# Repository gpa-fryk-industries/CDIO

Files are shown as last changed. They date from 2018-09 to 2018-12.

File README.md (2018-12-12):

# CDIO

## Hardware
Altium project and libraries are located in `hw/`. Schematics are available as PDF in `hw/board/`.

## Firmware
The firmware is split up in two. The MCU in `fw/mcu` and the FPGA in `fw/ice`. The README in `fw/` explains the 
configuration routine used for the FPGA.

See `fw/mcu/README-md` for instruction on how to compile the MCU firmware and dependencies.

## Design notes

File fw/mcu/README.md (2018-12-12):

# MCU Firmware

## src/
Main code directory

### fpga/
Contains code related to the FPGA

### fdt/
Contains code related to the device tree config file

### radio/
Contains code related to the radio

## Dependencies

### arm-non-eabi-*
Compiler used.

### device-tree-compiler
Used to compile the config.dts file into a flattened device tree binary read by the MCU during runtime. 

### Libopencm3
Open source ARM Cortex-M microcontroller library http://libopencm3.org/.
Included as a submodule in /fw/mcu/libopencm3.

**MUST BE COMPILED AFTER CLONING!**

### SPIRIT1_Library
Low level support library for radio. Located in /fw/mcu/radio/SPIRIT1_Library
Does not need to be compiled, included as-is.

## Compilation

### Install dependencies
All dependencies must be installed and in case of libopencm3, compiled.

### Run cmake
Run `cmake .` in the project root folder (not here). If successfully it should look something like this:
```
INFO * * * Device information * * *
INFO Device:	stm32l082kbu
INFO	family:	stm32l0 (stm32l082kbu)
INFO	cpu:	cortex-m0plus
INFO	fpu:	soft
INFO	flags:	-DSTM32L0 -DSTM32L082KBU
INFO	defs:	-DSTM32L0 -DSTM32L082KBU -D_ROM=128K -D_RAM=20K -D_ROM_OFF=0x08000000 -D_RAM_OFF=0x20000000
INFO libopencm3 libs: opencm3_stm32l0
INFO DTS @ /home/atmelfan/projects/CDIO/fw/mcu/src 
INFO FPGA CONFIGURATION @ /home/atmelfan/projects/CDIO/fw/mcu/src/fpga/fpga_conf.bin
-- Configuring done
-- Generating done
-- Build files have been written to: /home/atmelfan/projects/CDIO/cmake-build-debug
```

If device information is completely or partially empty, libopencm3 has most likely not been compiled properly or at the right location.

The `DTS @ <directory>` message should list the directory of the config.dts file.

The `FPGA CONFIGURATION @ <file>` message should specify the used FPGA configuration image.

### Compile
Run `make all`

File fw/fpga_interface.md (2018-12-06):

# FPGA Interface

## Physical
Pin assignments:

### Control signals
Pin names are written as `[HDL name]/[Schematic name]` when they do not match.

#### MCO_CLK/FPGA_GCLK 

FPGA clock. Is feed from the MCU using its MCO (Mcu Clock Out) functionality. 
Is divided by 2 from the MCU base clock of 4 MHz to 2 MHz. May be turned of in sleep mode.

#### RST/FPGA_RST
Resets the FPGA state. 

**Note** that ths is different from the CRESET pin below which is used to reset FPGA configuration!

#### ATT/FPGA_ATT
Interrupt request from the FPGA

#### MINH/FPGA_MINH
Master Inhibit. Not currently used. 

Reserved to inhibit the FPGA from behaving as master in a dual master system.

### SPI / config signals

#### SPI_SS/FPGA_CSS
SPI slave select. Selects the FPGA in both configuration mode and during normal operation. Active **LOW**.

#### SPI_SI/MOSI
SPI serial input.

#### SPI_SO/MISO
SPI serial output.

#### SPI_SCK/SCK
SPI serial clock.

#### CRESET/FPGA_CRESET
FPGA configuration reset. Resets configuration so that a new can be uploaded to config memory.

#### CDONE/FPGA_CDONE
FPGA configuration done. Indicates that configuration has been completed without error.

### Microphone signals

#### MIC_DAT/PDMD
Mic data. PDM encoded.

#### MIC_CLK/PDMC
Mic clock. Driven at 2 MHz when microphone is enabled.

### Speaker signals

#### SPK_R/PWMR 
Main speaker, right halfbridge PWM. 

#### SPK_L/PWML 
Main speaker, left halfbridge PWM. 

#### SPK_A/PWMA 
Aux speaker PWM. 

## Layout

The FPGA acts as a SPI slave with read/write registers. 

The first byte transferred contains a read or write bit (RW bit) and address. 

[0x00-0x3F - Config registers][0x40-0x7F - Data registers]

### Register read

1. Send address with MSB = 1
2. Read back

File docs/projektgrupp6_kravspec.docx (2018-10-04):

# Kravspecifikation

David Frykskog, Gustav Palmqvist

Version 3.0

# Status

Granskad
Godkänd

# PROJEKTIDENTITET

Grupp 6, 2018/HT, Deepoid AB CDIO
Linköpings Tekniska Högskola, ITN

# Gruppdeltagare

Namn | Ansvar | Telefon | E-post
Gustav Palmqvist | Projektledare (PL) | 070-455 84 40 | guspa885@student.liu.se
David Frykskog | Dokumentansvarig (DOK) | 070-372 27 11 | davfr422@student.liu.se

Kund: Deepoid AB, 583 30 Linköping,
Kontaktperson hos kund: Anders Brodin, 070-310 44 48 , anders@deepoid.com
Kursansvarig: Ole Pedersen, 011-36 32 61, ole.pedersen@liu.se
Handledare: Ole Pedersen, 011-36 32 61, ole.pedersen@liu.se

# Dokumenthistorik

Version | Datum | Utförda förändringar | Utförda av | Granskad
1.0 | 2018-09-06 | Första utkast | davfr422, guspa885
2.0 | 2018-09-23 | Revision 1 | davfr422, guspa885
3.0 | 2018-10-04 | Revision 2 | davfr422

# 1 Inledning

Deepoid AB i Linköping är ett företag som utvecklar och tar fram utrustning för dykarmarknaden. Företaget vill ta fram en prototyp för radiokommunikation mellan snorklare. Prototypen ska fungera för kommunikation på minst 100 meters avstånd och ska vara av lågenergityp. I huvudsak ska den första prototypen användas i labbmiljö, i syfte att vara ett underlag för en eventuell produkt.

## 1.1 Parter

Beställaren av prototypen är Deepoid AB och utförarna är civilingenjörsstudenter i elektronikdesign, år 5 (se författarna till dokumentet). Handledare från Linköpings universitet är även delaktiga för avstämning på handledningsmöten under projektets gång.

## 1.2 Mål

Målet med projektet är att utveckla en prototyp för radiokommunikation mellan snorklare. Företaget, eller beställaren vill ta del av prototypen i syfte att kunna utveckla det till en produkt.

## 1.3 Användning

Till en början ska prototypen som tidigare nämnt fungera som underlag för att utveckla en produkt för snorklare.

## 1.4 Definitioner

- AF – Audio Front end
- MCU – Microcontroller Unit
- FPGA/CPLD – Field-Programmable Gate Array/Complex-Programmable Logic Device
- PSU – Power Supply Unit
- RF – Radio Frequency / Radio Front end
- DSP – Digital Signal Processing
- ADC – Analog to Digital Converter
- DAC – Digital to Analog Converter
- D-DAC – DAC med klass D utgångssteg.

# 1 Översikt av systemet

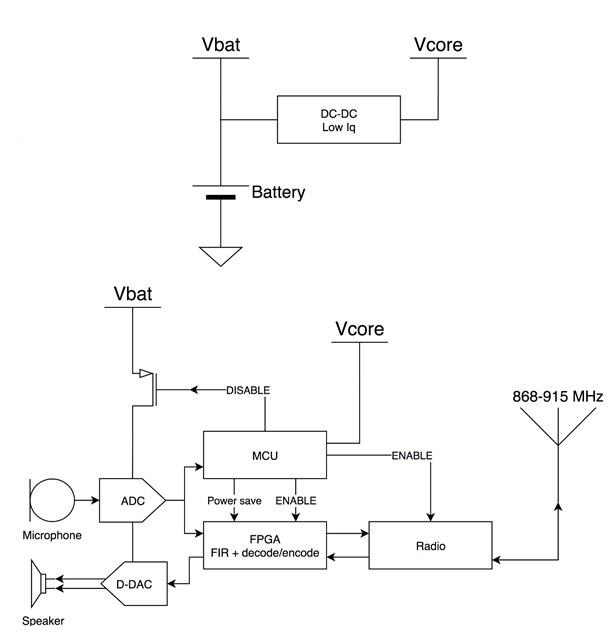
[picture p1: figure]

Figur 1: Översikt av systemet

## 1.1 Produktkomponenter

Som resultat av projektet kommer produkten bestå av flera prototyper mjukvara, underlag i form av layout och schema samt dokumentation. Fler än två prototyper är nödvändigt för att testa kommunikation inom grupp.

## 1.2 Beroenden till andra system

Systemet beror endast på andra enheter av samma typ (dvs inom sitt eget system).

## 1.3 Ingående delsystem

Prototypen består övergripligt av komponenter beskrivet i figur 1. Dessa monteras på ett PCB.

### 1.3.1 AF – Audio Front end

Består av mikrofon, högtalare, ADC och DAC med tillhörande förstärkare.

### 1.3.2 MCU – MicroController Unit

Mikrokontroller kontrollerar att samtliga enheter fungerar tillsammans samt sköter initialisering av systemet. MCU:n kommer majoriteten av tiden befinnas i sömnläge för att minimera strömförbrukning.

### 1.3.3 FPGA/CPLD – Field Programmable Gate Array

Strömsnål signalbehandlingsenhet som sköter filtrering (FIR) och formatering/paketering av en full duplex ljudström. Detta för att undvika utföra DSP i MCU:n vilket skulle kräva en kraftigare MCU med tillbehörande strömförbrukning.

### 1.3.4 PSU – Power Supply Unit

Strömförsörjningsenhet. Består av laddare till batteri och spänningsregulator till övrig elektronik.

### 1.3.5 RF – Radio Front end

Består av en tidigare godkänd radiomodul.

## 1.4 Avgränsningar

Systemet behöver inte ha någon specifik formfaktor (dvs. den behöver ej uppfylla något krav på form eller vikt) eller gå att använda i något annat än en testmiljö (under vatten).

## 1.5 Designfilosofi

Varje delsystem skall vara integrerat på ett kort men om möjligt vara tillräckligt isolerade så att om ett av delsystemen inte fungerar så ska det fortfarande gå att testa de andra. Det finns även en ekonomisk aspekt i val av hårdvara.

## 1.6 Generella krav på hela systemet

I detta dokument kommer alla krav att beskrivas med en tabellrad enligt nedan. Kravnummer kommer att vara löpande genom hela dokumentet. Kolumn två talar om att det är ett originalkrav eller om det har reviderats. Hänvisning till beslut om revidering ska finns. I kolumn 3 finns själva lydelsen av kravtexten. I sista kolumnen finns dess prioritet beskriven.

| Original | Systemet ska hantera röstkommunikation mellan enheter (multicasting). | Bas
| Original | Röstkommunikation ska alltid vara på, ingen ”push to talk”. | Bas
| Original | Minimal räckvidd: 100 m. | Bas
| Original | Önskat räckvidd: 500+ m. | Extra
| Original | Minimal batteritid: 10 h per enhet med kontinuerligt samtal. | Bas
| Original | Ska kunna hantera bruten kommunikationslänk och återansluta. | Bas
| Original | Systemet ska med enkelhet kunna bli godkänt av CE/FCC. | Bas
| Original | Användare anslutna till samma grupp/kanal ska endast kunna kommunicera inom gruppen/kanalen. | Bas
| Original | Minimalt röstspektrum: 300 – 3400 KHz | Bas
| Original | Skall inte använda kretsar som tillverkaren har markerad som ’Not recommended for new designs’ / NRND. | Extra

# 2 AF – Audio Front-end

Ljud-delsystemet kommer bestå av två komponenter.

- En ADC med 3.5mm ingång alternativt en mikrofon och förstärkare.
- En DAC med 3.5mm utgång alternativt en högtalare och förstärkare (klass D). Högtalaren har inga krav på effekt.

Två 3.5mm kontakter bör prioriteras då mikrofon och högtalare ej är ett krav och underlättar utveckling.

Audio front-end har som uppgift att omvandla den digitala ljudströmmen till dess analoga motsvarighet i båda riktningar.

För att uppfylla krav #5 så måste denna front end vara energieffektiv och gå att stänga av för att maximera batteritiden.

| Original | Energieffektiv audio front-end med avstängning. Derivat av krav #5. | Bas
| Original | ADC + DAC med minst 8 KHz samplingsfrekvens för röstkommunikation. | Bas
| Original | 3.5 mm kontakter för ljud in/ut under utveckling. | Bas
| Original | Integrerad mikrofon + högtalare med förstärkare. | Extra
| Original | Skall inte ta överhettas under normal användning. | Rev. 2

# 3 MCU

Mikrokontrollerenheten består av en mikrokontroller som sköter kontroll av samtliga enheter. Den har även uppgiften att initialisera FPGA:n.

Krav nr 16 D | Original | Mikrokontrollern ska kunna drivas på 1.8 V. | Bas
| Original | Mikrokontrollern ska befinna sig i sömnläge tills den triggas av en interrupt. | Bas

# 4 FPGA/CPLD

Krav nr 18 D | Original | Vid uppstart ska programvaran laddas över från MCU:n. | Bas
| Original | Ska kunna strömma ut data till radioenheten. | Bas
| Original | Ska sköta DSP av informationsbärande signaler för att avlasta MCU. DSP inkluderar LP filtrering, formatering och möjligen CRC av audio strömmen. | Bas

# 5 PSU

Krav nr 21 D | Original | Systemet ska kunna vara batteridrivet. | Bas
| Original | Batteriet ska kunna laddas genom USB. | Bas
Krav nr 23 F | Original | Switch-mode omvandlaren ska ha en effektivitet över 85% | Bas

# 6 RF – Radio Front end

Enligt krav nr 7 ovan så ska produkten gå att enkelt godkänna enligt FCC/CE krav vilket innebär att radiomodulen måste vara kompatibel med dessa krav. Detta kan undvikas genom att använda en redan godkänd modul.

Krav nr 24 D | Original | Ska bestå av CE/FCC godkänd modul. | Bas
| Original | Ska använda sig av 868 MHz / 915 MHz banden. | Bas
| Original | Radion ska gå att stänga av eller sättas i strömsparläge för att minimera effektförbrukning. | Extra

# 7 Prestandakrav

Hänvisar läsaren till generella krav på hela systemet (kap. 2.6).

# 8 Krav på möjlighet att uppgradera

| Original | Systemet ska kunna vidareutvecklas. | Bas

# 9 Ekonomi

| Original | Enhetskostnaden bör minimeras. | Extra

# 10 Krav på säkerhet

| Original | Batteriladdning får ej överladda batteriet eller djupurladda vilket kan leda till att batteriet fallerar. | Extra

# 11 Leveranskrav och delleveranser

| Original | Delleverans 2018-10-16: Layout och hårdvarubeställning. | Bas
| Original | Delleverans 2018-11-06: Hårdvara färdigställd. | Bas
| Original | Projektavslut 2018-12-18: Färdig prototyp. | Bas

# 12 Dokumentation

| Original | Första kravspecifikation färdig 2018-09-18. | Bas
| Original | Projektplan färdig 2018-09-18. | Bas
| Original | Tidsplan färdig 2018-09-18. | Bas
| Original | Projektrapport färdig 2019-01-07. | Bas

Projektkurs, CDIO. Projektgrupp 6 LIPs David Frykskog davfr422@student.liu.se Sida 13

LiTH Deepoid AB CDIO

LiTH Deepoid AB CDIO 2018-10-04

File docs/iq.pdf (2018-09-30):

Component | Name | Url/artnr | Manufacturer | Distributor | Cost, 1pc [USD]
FPGA | ICE40UP5K-SG48I | 842-40UP5KSG48ITR | Lattice | Mouser | 7,42
MCU | STM32L011F4U6TR | 511-STM32L011F4U6TR | STMicroelectronics | Mouser | 1,51
ADC | FAN3850AUC16X | 512-FAN3850AUC16X | ON Semiconductor | Mouser | 1,04
MIC | INMP621ACEZ-R7 | 410-INMP621ACEZ-R7 | Invensense | Mouser | 1,46
2xMOS (Class D output stage) | SSM6L61NU | 757-SSM6L61NULF | Toshiba | Mouser | 0,816
BUCK | TPS62740 | 595-TPS62740DSSR | Texas Instrumets | Mouser | 1,77
EUROPA | (moon of jupiter)
RADIO(868MHz, Europa) | SPSGRF-868 | 511-SPSGRF-868 | STMicroelectronics | Mouser | 15,75
| | | | Total: | 29,766

# AMERICA, JAPAN

RADIO(915MHz, America) | SPSGRF-915 | 511-SPSGRF-915 | STMicroelectronics | Mouser | 14,11
| | | | Total: | 28,126

Cost, 100pc [USD]
6,25
0,744
0,408
0,679
0,376
1,02

12,24
21,717

10,75
20,227

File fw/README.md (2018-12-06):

# Firmware
The firmware is split into two different parts, the MCU firmware and the FPGA firmware.

Both of these are contained in their respective directory.

## FPGA configuration
Most FPGA's requires an external memory to configure (this one, iCE40 does have a builtin OTP memory). 
To avoid having this (and not having to program two separate devices during dev) the FPGA is configured by the MCU.

The MCU stores a copy of the FPGA image in its flash memory which is then transferred on boot to the FPGA 
(see Lattice technical note `TN1248` for details). 

If the FPGA is programmed using its OTP memory, the MCU can skip this procedure (by commenting out `config-fpga` in `config.dts`) and possibly be downgraded to save cost.

Note that when updating the FPGA firmware, the resulting binary image `top_bitmap.bin` needs
to be copied into `/fw/mcu/fpga/fpga_conf.bin` where it's then linked into the MCU firmware.

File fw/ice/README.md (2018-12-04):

# FPGA Firmware
This directory contains the FPGA HDL code.

The root directory contains core packages, other packages should be sorted by their function into different module folders.
Top level entities is contained within `top_<name>/` directories and should contain configuration etc for synthesizing said entity. Top entities should import packages from root and its modules.

## LSE Synthesizer settings
Always weird, just fuck around with the settings until it works.

## Place & Route settings
### Bitmap
For the MCU->FPGA configuration to work these settings needs to be set:
* warmboot must be **disabled**
* Remove binary header must be **enabled**

If not, the FPGA will shit itself after configuration

## Top entities
Top entities is the entry point for synthesis. 

### - top_blinky
Contains simple test entity which toggles the ATT pin.

### - top_core
Contains the primary entity. Has ADPCM, VAD, FBI surveillance, buffers etc, the whole deal.

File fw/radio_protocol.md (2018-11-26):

# Radio protocol

## Data packets

All packages must begin with 8 bit packet id describing the packets function.

Packet format:
`[packet-id:8](payload:N*8)`

Syntax explanation; `[name:len]` denotes required data and `(name:len)` denotes optional data.

These id's are listed below:

### 0x00 - Nop | p2p, broadcast
No payload. Does nothing.

### 0x01 - Ping | p2p
No payload. Returns a Pong (0x02) to sender.

### 0x02 - Pong | p2p
No payload. Acts as a response tp Ping (0x01)

### 0xF0 - Message | p2p, broadcast
Payload contains message text formatted as a null terminated string. 

`[message:\n]`

### 0xF1 - Data | p2p, broadcast

`[channel:4][options:4][index:8][sample:16][adpcm_stream:4*128]`

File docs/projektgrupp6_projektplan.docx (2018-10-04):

# Projektplan

David Frykskog, Gustav Palmqvist

Version 2.0

# Status

Granskad
Godkänd

# PROJEKTIDENTITET

Grupp 6, 2018/HT, Deepoid AB CDIO
Linköpings Tekniska Högskola, ITN

# Gruppdeltagare

Namn | Ansvar | Telefon | E-post
Gustav Palmqvist | Projektledare (PL) | 070-455 84 40 | guspa885@student.liu.se
David Frykskog | Dokumentansvarig (DOK) | 070-372 27 11 | davfr422@student.liu.se

Kund: Deepoid AB, 583 30 Linköping,
Kontaktperson hos kund: Anders Brodin, 070-310 44 48 , anders@deepoid.com
Kursansvarig: Ole Pedersen, 011-36 32 61, ole.pedersen@liu.se
Handledare: Ole Pedersen, 011-36 32 61, ole.pedersen@liu.se

# 1. Beställare

Deepoid AB i Linköping är ett företag som utvecklar och tar fram utrustning för dykarmarknaden. Företaget vill ta fram en prototyp för radiokommunikation mellan snorklare. Prototypen ska fungera för kommunikation på minst 100 meters avstånd och ska vara av lågenergityp. I huvudsak ska den första prototypen användas i labbmiljö, i syfte att vara ett underlag för en eventuell produkt.

# 2. Översiktlig beskrivning av projektet

## 2.1. Mål

Målet med projektet är att utveckla en prototyp för radiokommunikation mellan snorklare. Företaget, eller beställaren vill ta del av prototypen i syfte att kunna utveckla det till en produkt.

## 2.2. Leveranser

Innan nyåret 2019 ska en prototyp vara färdig för demonstration för Deepoid AB och Linköpings universitet. Dessutom ska även samtlig dokumentation finnas tillgänglig samt tillhörande mjukvara i syfte att vidareutvecklas. Under tiden kommer även en delleverans ske vid halvtid med en färdigmonterad hårdvara redo att programmeras. För närmare information hänvisas läsaren till kravspecifikation kap. 12.

## 2.3. Begränsningar

I tillhörande kravspecifikation står det att prototypen endast testas i labbmiljö, och inte den avsedda miljön för den eventuellt framtida produkten. Prototypen kommer därför vara designad i en miljö som inte garanterar liknande förutsättningar som en snorklare upplever.

# 3. Dokumentplan

De dokument som produceras är kravspecifikation, projektplan, tidsplan och en slutrapport. Dokumenten kommer sedan distribueras till tekniska högskolan vid Linköpings universitet och Deepoid AB. För närmare datum hänvisas läsaren till kravspecifikationen under kap. 13. David Frykskog i projektgruppen ansvarar för dokumenten.

# 4. Utvecklingsmetodik

Produkten kommer i form av en prototyp som ska användas i utredningssyfte för att se ifall den kan realiseras till en produkt. Därför kommer utvecklingsarbetet ta hänsyn till internationella standarder och regelverk samt kostnad exempelvis. Detta kommer underlätta för att senare utreda ifall prototypen kan vidareutvecklas till en produkt som ska kunna säljas på marknaden.

# 5. Rapporteringsplan

Som en del av arbetet skall en slutrapport skrivas. Denna ska enbart skrivas av Fryk då Gustav ej bryr sig. Rapporten ska vara färdig innan 2019-01-07.

# 6. Mötesplan

Varje vecka skall ett möte hållas med kursansvarig och vid behov handledare eller kund.

# 7. Resursplan

## 7.1. Personer

Kursansvarige – Handledare.

Qin-Zhong Ye – Frågor angående DSP.

## 7.2. Lokaler och materiel

På universitetet finns tillgång till lokaler med datorer med olika utvecklingsverktyg och mätutrustning. Dessutom finns en verkstad och ett mönsterkortslabb som kan användas.

# 8. Milstolpar och beslutspunkter

## 8.1. Milstolpar

- Layout färdig och hårdvarubeställning lagd: 2018-10-16.
- Hårdvara färdigställd/monterad: 2018-11-06.
- Projektavslut, färdig prototyp: 2018-12-18.
- Projektrapport färdig: 2019-01-07.

## 8.2. Beslutspunkter

- Avstämningsmöte med examinator varje vecka.
- Avstämning med Deepoid AB vid behov.

# 9. Aktiviteter

Nr | Aktivitet | Beskrivning | Beräknad tid tim
| Dokumentation | Skriva kravspecifikation | 20
| Dokumentation | Skriva projektplan | 16
| Dokumentation | Skriva tidsplan | 8
| Forskning | Vad krävs för röstkommunikation? | 8
| Ekonomisk planering | Kostnadsanalys | 8
| Schemaritning | Rita blockdiagram | 12
| CAD | Rita kretsschema i Altium Designer | 24
| CAD | Rita layout i Altium Designer för mönsterkort | 40
| CAD | Granska kretsschema och layout | 8
| Beställning | Beställa komponenter till projektet | 2
| Tillverkning | Montera komponenter på PCB | 16
| Programmering | Konfigurera programmeringsmiljö och verktyg | 24
| Programmering | MCU | 40
| Programmering | FPGA | 112
| Programmering | Bugfix | NaN
| Rapport | Ineffektivt arbete + riktigt arbete | 64

# 10. Systemskiss


Figur 1: Systemskiss

# 11.Tidsplan

Läsaren hänvisas till tillhörande dokument för tidsplan.

# 12. Kvalitetsplan

Alla prototyper skall testas utifrån kravspec.

# 13. Projektavslut

Projektet bör avslutas med ett komplett system test (överföring av röst, kontroll av batteri tid, räckvidd etc. enligt kravspec).

Projektkurs, CDIO Projektgrupp 6 LIPs David Frykskog davfr422@student.liu.se Sida 8

Projektkurs, CDIO Projektgrupp 6 LIPs David Frykskog davfr422@student.liu.se Sida 3

LiTH Deepoid AB CDIO

LiTH Deepoid AB CDIO 2018-10-04

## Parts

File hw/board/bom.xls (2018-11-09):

Line # | Name | Description | Designator | Variant | Quantity | Total Quantity | value | type | Manufacturer 1 | Manufacturer Part Number 1 | Supplier 1 | Supplier Part Number 1 | Supplier 2 | Supplier Part Number 2 | Supplier 3 | Supplier Part Number 3
1 | cap | Capacitor | C1, C2, C6, C24, C25, C29 | EUROPE | 6 | 18 | 10u | X5R | TDK (https://octopart-clicks.com/click/altium?sku=810-C3216X5R1C106M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) | C3216X5R1C106M160AA (https://octopart-clicks.com/click/altium?sku=810-C3216X5R1C106M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) | Mouser | 810-C3216X5R1C106M (https://octopart-clicks.com/click/altium?sku=810-C3216X5R1C106M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)
2 | cap | Capacitor | C3, C7, C8, C9, C11, C12, C13, C15, C16, C17, C20, C21, C22, C26, C27, C28 | EUROPE | 16 | 48 | 100n | X7R | Murata (https://octopart-clicks.com/click/altium?sku=81-GCM155R71H103KA5J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) | GCM155R71H103KA55J (https://octopart-clicks.com/click/altium?sku=81-GCM155R71H103KA5J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) | Mouser | 81-GCM155R71H103KA5J (https://octopart-clicks.com/click/altium?sku=81-GCM155R71H103KA5J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)
3 | cap | Capacitor | C4, C5, C19, C23 | EUROPE | 4 | 12 | 1u | X7R | Vishay Vitramon (https://octopart-clicks.com/click/altium?manufacturer=Vishay%20Vitramon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) | VJ0805Y105MXQTW1BC (https://octopart-clicks.com/click/altium?manufacturer=Vishay%20Vitramon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) | Mouser | 77-VJ0805Y105MXQTBC (https://octopart-clicks.com/click/altium?manufacturer=Vishay%20Vitramon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)
4 | cap | Capacitor | C10, C14, C18 | EUROPE | 3 | 9 | 4u7 | X5R | Wurth Electronics (https://octopart-clicks.com/click/altium?sku=710-885012107009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) | 885012107009 (https://octopart-clicks.com/click/altium?sku=710-885012107009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) | Mouser | 710-885012107009 (https://octopart-clicks.com/click/altium?sku=710-885012107009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)
5 | cap | Capacitor | C30 | EUROPE | 1 | 3 | 10n | X7R | LiTHeEl (https://octopart-clicks.com/click/altium?sku=Sortiment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) | Sortiment (https://octopart-clicks.com/click/altium?sku=Sortiment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) | LiTHeEl | Sortiment (https://octopart-clicks.com/click/altium?sku=Sortiment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)
6 | ferrite | Inductor | FB1, FB2 | EUROPE | 2 | 6 | 100R |  | TDK (https://octopart-clicks.com/click/altium?sku=810-MMZ1005S102HT000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) | MMZ1005S102HT000 (https://octopart-clicks.com/click/altium?sku=810-MMZ1005S102HT000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) | Mouser | 810-MMZ1005S102HT000 (https://octopart-clicks.com/click/altium?sku=810-MMZ1005S102HT000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)
7 | res | Resistor | J2, J4 | EUROPE | 2 | 6 | 0R |  | LiTHeEl (https://octopart-clicks.com/click/altium?sku=Sortiment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) | Sortiment (https://octopart-clicks.com/click/altium?sku=Sortiment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) | LiTHeEl | Sortiment (https://octopart-clicks.com/click/altium?sku=Sortiment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)
8 | iCE40 Prog | 2x5 Header | J5 | EUROPE | 1 | 3 |  |  | Samtec (https://octopart-clicks.com/click/altium?sku=200-FTSH10501LDVKTR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) | FTSH-105-01-L-DV-K-TR (https://octopart-clicks.com/click/altium?sku=200-FTSH10501LDVKTR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) | Mouser | 200-FTSH10501LDVKTR (https://octopart-clicks.com/click/altium?sku=200-FTSH10501LDVKTR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)
9 | SWD | SWD Header | J6 | EUROPE | 1 | 3 |  |  | Samtec (https://octopart-clicks.com/click/altium?sku=200-FTSH10501LDVKTR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) | FTSH-105-01-L-DV-K-TR (https://octopart-clicks.com/click/altium?sku=200-FTSH10501LDVKTR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) | Mouser | 200-FTSH10501LDVKTR (https://octopart-clicks.com/click/altium?sku=200-FTSH10501LDVKTR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)
10 | 53 | Cylindrical Battery Contacts, Clips, Holders & Springs SMT Battery clip FOR AA | J7, J8, J9, J10 | EUROPE | 4 | 12 |  |  | Keystone Electronics (https://octopart-clicks.com/click/altium?sku=534-53TR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) | 53TR (https://octopart-clicks.com/click/altium?sku=534-53TR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) | Mouser | 534-53TR (https://octopart-clicks.com/click/altium?sku=534-53TR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)
11 | SJ-43504-SMT-TR | MID MOUNT AUDIO JACK | J11 | EUROPE | 1 | 3 |  |  | CUI (https://octopart-clicks.com/click/altium?sku=490-SJ-43504-SMT-TR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) | SJ-43504-SMT-TR (https://octopart-clicks.com/click/altium?sku=490-SJ-43504-SMT-TR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) | Mouser | 490-SJ-43504-SMT-TR (https://octopart-clicks.com/click/altium?sku=490-SJ-43504-SMT-TR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)
12 | ind | Inductor | L1 | EUROPE | 1 | 3 | 2u2 |  | Taiyo Yuden (https://octopart-clicks.com/click/altium?sku=963-LB3218T2R2M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) | LB3218T2R2M (https://octopart-clicks.com/click/altium?sku=963-LB3218T2R2M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) | Mouser | 963-LB3218T2R2M (https://octopart-clicks.com/click/altium?sku=963-LB3218T2R2M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) | RSComponents | 755-4703 (https://octopart-clicks.com/click/altium?sku=755-4703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)
13 | CMS-15113-078S | Speakers & Transducers 0.7W 8ohm 700Hz 15x11mm SpringContct | LS1 | EUROPE | 1 | 3 |  |  | CUI (https://octopart-clicks.com/click/altium?sku=490-CMS-15113-078S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) | CMS-15113-078S (https://octopart-clicks.com/click/altium?sku=490-CMS-15113-078S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) | Mouser | 490-CMS-15113-078S (https://octopart-clicks.com/click/altium?sku=490-CMS-15113-078S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)
14 | RU1J002YN | N-channel 50V 200mA Small signal MOSFET | Q2, Q3, Q4 | EUROPE | 3 | 9 |  |  | Rohm (https://octopart-clicks.com/click/altium?sku=755-RU1J002YNTCL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) | RU1J002YNTCL (https://octopart-clicks.com/click/altium?sku=755-RU1J002YNTCL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) | Mouser | 755-RU1J002YNTCL (https://octopart-clicks.com/click/altium?sku=755-RU1J002YNTCL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) | RSComponents | 1246836P (https://octopart-clicks.com/click/altium?sku=1246836P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)
15 | res | Resistor | R1, R9, R14, R15, R17, R18, R24 | EUROPE | 7 | 21 | 10K |  | LiTHeEl (https://octopart-clicks.com/click/altium?sku=Sortiment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) | Sortiment (https://octopart-clicks.com/click/altium?sku=Sortiment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) | LiTHeEl | Sortiment (https://octopart-clicks.com/click/altium?sku=Sortiment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)
16 | res | Resistor | R2, R3, R5, R8, R16, R27 | EUROPE | 6 | 18 | 47K |  | LiTHeEl (https://octopart-clicks.com/click/altium?sku=Sortiment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) | Sortiment (https://octopart-clicks.com/click/altium?sku=Sortiment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) | LiTHeEl | Sortiment (https://octopart-clicks.com/click/altium?sku=Sortiment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)
17 | res | Resistor | R6, R7, R12, R13, R23 | EUROPE | 5 | 15 | 1K |  | LiTHeEl (https://octopart-clicks.com/click/altium?sku=Sortiment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) | Sortiment (https://octopart-clicks.com/click/altium?sku=Sortiment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) | LiTHeEl | Sortiment (https://octopart-clicks.com/click/altium?sku=Sortiment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)
18 | res | Resistor | R10 | EUROPE | 1 | 3 | 270K |  | LiTHeEl (https://octopart-clicks.com/click/altium?sku=Sortiment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) | Sortiment (https://octopart-clicks.com/click/altium?sku=Sortiment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) | LiTHeEl | Sortiment (https://octopart-clicks.com/click/altium?sku=Sortiment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)
19 | res | Resistor | R11, R20 | EUROPE | 2 | 6 | 100K |  | LiTHeEl (https://octopart-clicks.com/click/altium?sku=Sortiment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) | Sortiment (https://octopart-clicks.com/click/altium?sku=Sortiment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) | LiTHeEl | Sortiment (https://octopart-clicks.com/click/altium?sku=Sortiment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)
20 | res | Resistor | R19 | EUROPE | 1 | 3 | 1M2 |  | LiTHeEl (https://octopart-clicks.com/click/altium?sku=Sortiment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) | Sortiment (https://octopart-clicks.com/click/altium?sku=Sortiment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) | LiTHeEl | Sortiment (https://octopart-clicks.com/click/altium?sku=Sortiment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)
21 | res | Resistor | R21 | EUROPE | 1 | 3 | 2K2 |  | LiTHeEl (https://octopart-clicks.com/click/altium?sku=Sortiment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) | Sortiment (https://octopart-clicks.com/click/altium?sku=Sortiment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) | LiTHeEl | Sortiment (https://octopart-clicks.com/click/altium?sku=Sortiment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)
22 | res | Resistor | R22 | EUROPE | 1 | 3 | 10R |  | LiTHeEl (https://octopart-clicks.com/click/altium?sku=Sortiment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) | Sortiment (https://octopart-clicks.com/click/altium?sku=Sortiment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) | LiTHeEl | Sortiment (https://octopart-clicks.com/click/altium?sku=Sortiment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)
23 | res | Resistor | R25 | EUROPE | 1 | 3 | 220K |  | LiTHeEl (https://octopart-clicks.com/click/altium?sku=Sortiment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) | Sortiment (https://octopart-clicks.com/click/altium?sku=Sortiment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) | LiTHeEl | Sortiment (https://octopart-clicks.com/click/altium?sku=Sortiment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)
24 | res | Resistor | R26 | EUROPE | 1 | 3 | 390K |  | LiTHeEl (https://octopart-clicks.com/click/altium?sku=Sortiment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) | Sortiment (https://octopart-clicks.com/click/altium?sku=Sortiment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) | LiTHeEl | Sortiment (https://octopart-clicks.com/click/altium?sku=Sortiment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)
25 | SPSGRF-868 | Sub-GHz (868 or 915 MHz) low power programmable RF | RF1 | EUROPE | 1 | 3 |  |  | STMicroelectronics (https://octopart-clicks.com/click/altium?sku=511-SPSGRF-868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) | SPSGRF-868 (https://octopart-clicks.com/click/altium?sku=511-SPSGRF-868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) | Mouser | 511-SPSGRF-868 (https://octopart-clicks.com/click/altium?sku=511-SPSGRF-868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)
26 | PTS840ESDPKSMTRLFS | Microminiature SMT Side Actuated tactile switch | S1 | EUROPE | 1 | 3 |  |  | ITT C&K (https://octopart-clicks.com/click/altium?sku=611-PTS840ESDPKSMTR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) | PTS840ESDPKSMTRLFS (https://octopart-clicks.com/click/altium?sku=611-PTS840ESDPKSMTR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) | Mouser | 611-PTS840PKSMTR (https://octopart-clicks.com/click/altium?sku=611-PTS840PKSMTR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) | RSComponents | 1359213 (https://octopart-clicks.com/click/altium?sku=1359213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)
27 | SLLB120300 | Compact and low-profile horizontal type for various applications | S2 | EUROPE | 1 | 3 |  |  | Alps Electric (https://octopart-clicks.com/click/altium?sku=688-SLLB120300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) | SLLB120300 (https://octopart-clicks.com/click/altium?sku=688-SLLB120300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) | Mouser | 688-SLLB120300 (https://octopart-clicks.com/click/altium?sku=688-SLLB120300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) | RSComponents | 1239641 (https://octopart-clicks.com/click/altium?sku=1239641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)
28 | iCE40UP5K | iCE40 UltraPlus family ultra-low power FPGA | U1 | EUROPE | 1 | 3 |  |  | Lattice Semiconductor (https://octopart-clicks.com/click/altium?manufacturer=Lattice%20Semiconductor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) | ICE40UP5K-SG48ITR (https://octopart-clicks.com/click/altium?manufacturer=Lattice%20Semiconductor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) | Mouser | 842-40UP5KSG48ITR (https://octopart-clicks.com/click/altium?manufacturer=Lattice%20Semiconductor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)
29 | TPS62740DSSR | TPS6274x 360nA IQ Step Down Converter For Low Power Applications | U2 | EUROPE | 1 | 3 |  |  | Texas Instruments (https://octopart-clicks.com/click/altium?sku=595-TPS62740DSSR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) | TPS62740DSSR (https://octopart-clicks.com/click/altium?sku=595-TPS62740DSSR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) | Mouser | 595-TPS62740DSSR (https://octopart-clicks.com/click/altium?sku=595-TPS62740DSSR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) | RSComponents | 825-7018P | Mouser | 595-TPS62740DSST
30 | STM32L082KBU6 | Ultra-low-power 32-bit MCU Arm-based Cortex-M0+, up to 192KB Flash, 20KB SRAM, 6KB EEPROM, USB, ADC, DACs, AES | U3 | EUROPE | 1 | 3 |  |  | STMicroelectronics (https://octopart-clicks.com/click/altium?sku=511-STM32L082KBU6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) | STM32L082KBU6 (https://octopart-clicks.com/click/altium?sku=511-STM32L082KBU6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) | Mouser | 511-STM32L082KBU6 (https://octopart-clicks.com/click/altium?sku=511-STM32L082KBU6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)
31 | TPS7A0512 | TPS7A05 1-µA Ultralow IQ, 200-mA, Low-Dropout Regulator | U4 | EUROPE | 1 | 3 |  |  | Texas Instruments (https://octopart-clicks.com/click/altium?manufacturer=Texas%20Instruments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) | TPS7A0512PDBVR (https://octopart-clicks.com/click/altium?manufacturer=Texas%20Instruments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) | Mouser | 595-TPS7A0512PDBVR (https://octopart-clicks.com/click/altium?manufacturer=Texas%20Instruments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)
32 | FAN3850AUC16X | Microphone Pre-Amplifier with Digital Output | U5 | EUROPE | 1 | 3 |  |  | ON Semiconductor / Fairchild (https://octopart-clicks.com/click/altium?manufacturer=ON%20Semiconductor%20%2F%20Fairchild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) | FAN3850AUC16X (https://octopart-clicks.com/click/altium?manufacturer=ON%20Semiconductor%20%2F%20Fairchild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) | Mouser | 512-FAN3850AUC16X (https://octopart-clicks.com/click/altium?manufacturer=ON%20Semiconductor%20%2F%20Fairchild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) | RSComponents | 760-5794 (https://octopart-clicks.com/click/altium?manufacturer=ON%20Semiconductor%20%2F%20Fairchild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)
33 | SSM6L61NU,LF | 2 MOSFET in one package. 1 NMOS and one PMOS. | U6, U7, U9 | EUROPE | 3 | 9 |  |  | Diodes (https://octopart-clicks.com/click/altium?sku=621-DMC1030UFDB-7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) | DMC1030UFDB-7 (https://octopart-clicks.com/click/altium?sku=621-DMC1030UFDB-7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) | Mouser | 621-DMC1030UFDB-7 (https://octopart-clicks.com/click/altium?sku=621-DMC1030UFDB-7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) | Mouser | 757-SSM6L61NULF
34 | INMP621 | Wide Dynamic Range Microphone with PDM Digital Output | U8 | EUROPE | 1 | 3 |  |  | TDK InvenSense (https://octopart-clicks.com/click/altium?sku=410-INMP621ACEZ-R7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) | INMP621ACEZ-R7 (https://octopart-clicks.com/click/altium?sku=410-INMP621ACEZ-R7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) | Mouser | 410-INMP621ACEZ-R7 (https://octopart-clicks.com/click/altium?sku=410-INMP621ACEZ-R7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)
 |  |  |  |  | Num boards: | 3

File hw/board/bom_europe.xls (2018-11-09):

Comment | Description | Designator | Quantity | value | type | Footprint | Manufacturer 1 | Manufacturer Part Number 1 | Supplier 1 | Supplier Part Number 1 | Supplier 2 | Supplier Part Number 2 | Supplier 3 | Supplier Part Number 3
cap | Capacitor | C1 | 1 | 10u | X5R | CAPC3216X14N |  |  | Mouser | 810-C3216X5R1C106M
cap | Capacitor | C2 | 1 | 10u | X5R | CAPC3216X14N |  |  | Mouser | 810-C3216X5R1C106M
cap | Capacitor | C3 | 1 | 100n | X7R | CAPC1005X06N |  |  | Mouser | 81-GCM155R71H103KA5J
cap | Capacitor | C4 | 1 | 1u | X7R | CAPC2012X11N |  |  | Mouser | 77-VJ0805Y105MXQTBC
cap | Capacitor | C5 | 1 | 1u | X7R | CAPC2012X11N |  |  | Mouser | 77-VJ0805Y105MXQTBC
cap | Capacitor | C6 | 1 | 10u | X5R | CAPC3216X14N |  |  | Mouser | 810-C3216X5R1C106M
cap | Capacitor | C7 | 1 | 100n | X7R | CAPC1005X06N |  |  | Mouser | 81-GCM155R71H103KA5J
cap | Capacitor | C8 | 1 | 100n | X7R | CAPC1005X06N |  |  | Mouser | 81-GCM155R71H103KA5J
cap | Capacitor | C9 | 1 | 100n | X7R | CAPC1005X06N |  |  | Mouser | 81-GCM155R71H103KA5J
cap | Capacitor | C10 | 1 | 4u7 | X5R | CAPC2012X11N |  |  | Mouser | 710-885012107009
cap | Capacitor | C11 | 1 | 100n | X7R | CAPC1005X06N |  |  | Mouser | 81-GCM155R71H103KA5J
cap | Capacitor | C12 | 1 | 100n | X7R | CAPC1005X06N |  |  | Mouser | 81-GCM155R71H103KA5J
cap | Capacitor | C13 | 1 | 100n | X7R | CAPC1005X06N |  |  | Mouser | 81-GCM155R71H103KA5J
cap | Capacitor | C14 | 1 | 4u7 | X5R | CAPC2012X11N |  |  | Mouser | 710-885012107009
cap | Capacitor | C15 | 1 | 100n | X7R | CAPC1005X06N |  |  | Mouser | 81-GCM155R71H103KA5J
cap | Capacitor | C16 | 1 | 100n | X7R | CAPC1005X06N |  |  | Mouser | 81-GCM155R71H103KA5J
cap | Capacitor | C17 | 1 | 100n | X7R | CAPC1005X06N |  |  | Mouser | 81-GCM155R71H103KA5J
cap | Capacitor | C18 | 1 | 4u7 | X5R | CAPC2012X11N |  |  | Mouser | 710-885012107009
cap | Capacitor | C19 | 1 | 1u | X7R | CAPC2012X11N |  |  | Mouser | 77-VJ0805Y105MXQTBC
cap | Capacitor | C20 | 1 | 100n | X7R | CAPC1005X06N |  |  | Mouser | 81-GCM155R71H103KA5J
cap | Capacitor | C21 | 1 | 100n | X7R | CAPC1005X06N |  |  | Mouser | 81-GCM155R71H103KA5J
cap | Capacitor | C22 | 1 | 100n | X7R | CAPC1005X06N |  |  | Mouser | 81-GCM155R71H103KA5J
cap | Capacitor | C23 | 1 | 1u | X7R | CAPC2012X11N |  |  | Mouser | 77-VJ0805Y105MXQTBC
cap | Capacitor | C24 | 1 | 10u | X5R | CAPC3216X14N |  |  | Mouser | 810-C3216X5R1C106M
cap | Capacitor | C25 | 1 | 10u | X5R | CAPC3216X14N |  |  | Mouser | 810-C3216X5R1C106M
cap | Capacitor | C26 | 1 | 100n | X7R | CAPC1005X06N |  |  | Mouser | 81-GCM155R71H103KA5J
cap | Capacitor | C27 | 1 | 100n | X7R | CAPC1005X06N |  |  | Mouser | 81-GCM155R71H103KA5J
cap | Capacitor | C28 | 1 | 100n | X7R | CAPC1005X06N |  |  | Mouser | 81-GCM155R71H103KA5J
cap | Capacitor | C29 | 1 | 10u | X5R | CAPC3216X14N |  |  | Mouser | 810-C3216X5R1C106M
cap | Capacitor | C30 | 1 | 10n | X7R | CAPC1005X06N
ferrite | Inductor | FB1 | 1 | 100R |  | INDC1005X06N |  |  | Mouser | 810-MMZ1005S102HT000
ferrite | Inductor | FB2 | 1 | 100R |  | INDC1005X06N |  |  | Mouser | 810-MMZ1005S102HT000
res | Resistor | J2 | 1 | 0R |  | RESC1005X04N
res | Resistor | J4 | 1 | 0R |  | RESC1005X04N
iCE40 Prog | 2x5 Header | J5 | 1 |  |  | hdr_2x5_50mil |  |  | Mouser | 200-FTSH10501LDVKTR
SWD | SWD Header | J6 | 1 |  |  | hdr_2x5_50mil |  |  | Mouser | 200-FTSH10501LDVKTR
53 | Cylindrical Battery Contacts, Clips, Holders & Springs SMT Battery clip FOR AA | J7 | 1 |  |  | ke53 |  |  | Mouser | 534-53TR | Digi-Key | 36-53CT-ND
53 | Cylindrical Battery Contacts, Clips, Holders & Springs SMT Battery clip FOR AA | J8 | 1 |  |  | ke53 |  |  | Mouser | 534-53TR | Digi-Key | 36-53CT-ND
53 | Cylindrical Battery Contacts, Clips, Holders & Springs SMT Battery clip FOR AA | J9 | 1 |  |  | ke53 |  |  | Mouser | 534-53TR | Digi-Key | 36-53CT-ND
53 | Cylindrical Battery Contacts, Clips, Holders & Springs SMT Battery clip FOR AA | J10 | 1 |  |  | ke53 |  |  | Mouser | 534-53TR | Digi-Key | 36-53CT-ND
SJ-43504-SMT-TR | MID MOUNT AUDIO JACK | J11 | 1 |  |  | SJ-43504-SMT-TR |  |  | Mouser | 490-SJ-43504-SMT-TR
ind | Inductor | L1 | 1 | 2u2 |  | INDC3216X20N |  |  | Mouser | 963-LB3218T2R2M | RSComponents | 755-4703
CMS-15113-078S | Speakers & Transducers 0.7W 8ohm 700Hz 15x11mm SpringContct | LS1 | 1 |  |  | cms-15113-078s |  |  | Mouser | 490-CMS-15113-078S
RU1J002YN | N-channel 50V 200mA Small signal MOSFET | Q2 | 1 |  |  | SOTFL65P210X105-3N |  |  | RSComponents | 1246836P | Mouser | 755-RU1J002YNTCL
RU1J002YN | N-channel 50V 200mA Small signal MOSFET | Q3 | 1 |  |  | SOTFL65P210X105-3N |  |  | RSComponents | 1246836P | Mouser | 755-RU1J002YNTCL
RU1J002YN | N-channel 50V 200mA Small signal MOSFET | Q4 | 1 |  |  | SOTFL65P210X105-3N |  |  | RSComponents | 1246836P | Mouser | 755-RU1J002YNTCL
res | Resistor | R1 | 1 | 10K |  | RESC1005X04N
res | Resistor | R2 | 1 | 47K |  | RESC1005X04N
res | Resistor | R3 | 1 | 47K |  | RESC1005X04N
res | Resistor | R5 | 1 | 47K |  | RESC1005X04N
res | Resistor | R6 | 1 | 1K |  | RESC1005X04N
res | Resistor | R7 | 1 | 1K |  | RESC1005X04N
res | Resistor | R8 | 1 | 47K |  | RESC1005X04N
res | Resistor | R9 | 1 | 10K |  | RESC1005X04N
res | Resistor | R10 | 1 | 270K |  | RESC1005X04N
res | Resistor | R11 | 1 | 100K |  | RESC1005X04N
res | Resistor | R12 | 1 | 1K |  | RESC1005X04N
res | Resistor | R13 | 1 | 1K |  | RESC1005X04N
res | Resistor | R14 | 1 | 10K |  | RESC1005X04N
res | Resistor | R15 | 1 | 10K |  | RESC1005X04N
res | Resistor | R16 | 1 | 47K |  | RESC1005X04N
res | Resistor | R17 | 1 | 10K |  | RESC1005X04N
res | Resistor | R18 | 1 | 10K |  | RESC1005X04N
res | Resistor | R19 | 1 | 1M2 |  | RESC1005X04N
res | Resistor | R20 | 1 | 100K |  | RESC1005X04N
res | Resistor | R21 | 1 | 2K2 |  | RESC1005X04N
res | Resistor | R22 | 1 | 10R |  | RESC2012X06N
res | Resistor | R23 | 1 | 1K |  | RESC1005X04N
res | Resistor | R24 | 1 | 10K |  | RESC1005X04N
res | Resistor | R25 | 1 | 220K |  | RESC1005X04N
res | Resistor | R26 | 1 | 390K |  | RESC1005X04N
res | Resistor | R27 | 1 | 47K |  | RESC1005X04N
SPSGRF-868 | Sub-GHz (868 or 915 MHz) low power programmable RF | RF1 | 1 |  |  | spsgrf |  |  | Mouser | 511-SPSGRF-868
PTS840ESDPKSMTRLFS | Microminiature SMT Side Actuated tactile switch | S1 | 1 |  |  | PCBComponent_1 |  |  | Mouser | 611-PTS840ESDPKSMTR | RSComponents | 1359213
SLLB120300 | Compact and low-profile horizontal type for various applications | S2 | 1 |  |  | sllb120300 |  |  | Mouser | 688-SLLB120300 | RSComponents | 1239641
iCE40UP5K | iCE40 UltraPlus family from Lattice Semiconductor is an ultra-low power FPGA and sensor manager designed for ultra - low power mobile a pplications, such as smartphones, tablets and hand-held devices. | U1 | 1 |  |  | QFN127P600-8N-ICE40UP5K |  |  | Mouser | 842-40UP5KSG48ITR | Digi-Key | 220-2145-1-ND
TPS62740DSSR | TPS6274x 360nA IQ Step Down Converter For Low Power Applications | U2 | 1 |  |  | SON50P200X80_HS-13N |  |  | Mouser | 595-TPS62740DSSR | RSComponents | 825-7018P | Mouser | 595-TPS62740DSST
STM32L082KBU6 | Ultra-low-power 32-bit MCU Arm-based Cortex-M0+, up to 192KB Flash, 20KB SRAM, 6KB EEPROM, USB, ADC, DACs, AES | U3 | 1 |  |  | QFN50P500X500X60_HS-33N |  |  | Mouser | 511-STM32L082KBU6 | Digi-Key | STM32L082KBU6-ND
TPS7A0512 | TPS7A05 1-µA Ultralow IQ, 200-mA, Low-Dropout Regulator | U4 | 1 |  |  | SOT95P280X145-5N |  |  | Mouser | 595-TPS7A0512PDBVR
FAN3850AUC16X | Microphone Pre-Amplifier with Digital Output | U5 | 1 |  |  | BGA6C48P2X3_86X126X30 |  |  | RSComponents | 760-5794 | Mouser | 512-FAN3850AUC16X | Digi-Key | FAN3850AUC16XFSCT-ND
SSM6L61NU,LF | 2 MOSFET in one package. 1 NMOS and one PMOS. | U6 | 1 |  |  | SON65P200X80_HS-7N |  |  | Mouser | 621-DMC1030UFDB-7 | Mouser | 757-SSM6L61NULF | Digi-Key | SSM6L61NULFCT-ND
SSM6L61NU,LF | 2 MOSFET in one package. 1 NMOS and one PMOS. | U7 | 1 |  |  | SON65P200X80_HS-7N |  |  | Mouser | 621-DMC1030UFDB-7 | Mouser | 757-SSM6L61NULF | Digi-Key | SSM6L61NULFCT-ND
INMP621 | Wide Dynamic Range Microphone with PDM Digital Output | U8 | 1 |  |  | SON70P300X90-4N |  |  | Mouser | 410-INMP621ACEZ-R7 | Digi-Key | 1428-1018-1-ND
SSM6L61NU,LF | 2 MOSFET in one package. 1 NMOS and one PMOS. | U9 | 1 |  |  | SON65P200X80_HS-7N |  |  | Mouser | 621-DMC1030UFDB-7 | Mouser | 757-SSM6L61NULF | Digi-Key | SSM6L61NULFCT-ND

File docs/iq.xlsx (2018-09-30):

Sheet: Sheet2
STM32F429xx |  |  | $10.94
freq | #samples | tot | t/sample | CPU Utilization at 8ksps | Iactive | Isleep | Iavg
180000000 | 320 | 0.000169 | 5.28125e-07 | 0.42% | 0.044 | 0.021 | 0.021097175
90000000 | 320 | 0.000338 | 1.05625e-06 | 0.84% | 0.02 | 0.008 | 0.0081014
16000000 | 320 | 0.00190125 | 5.94140625e-06 | 4.75% | 0.007 | 0.003 | 0.003190125
2000000 | 320 | 0.01521 | 4.753125e-05 | 38.02% | 0.002 | 0.002 | 0.002
FIR performance data from AN4841
ICE40UP5K-SG48I |  |  | $6.06 | 5280 LUTs
Static Iq | Dynamic | Iavg
7.655e-05 | << 1mA | << 1mA
Estimated FIR dynamic power consumption
http://www.latticesemi.com/-/media/LatticeSemi/Documents/UserManuals/EI2/FPGA-EB-02007-1-1-iCE40-UltraPlus-Mobile-Development-Platform.ashx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
ICE40LPxxx |  |  | $3-8 | 384 - 7680 LUTS

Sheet: Sheet1
Component | Name | Url/artnr | Manufacturer | Distributor | Cost, 1pc [USD] | Cost, 100pc [USD]
FPGA | ICE40UP5K-SG48I | 842-40UP5KSG48ITR (https://www.mouser.se/ProductDetail/Lattice/ICE40UP5K-SG48ITR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) | Lattice | Mouser | 7.42 | 6.25
MCU | STM32L011F4U6TR | 511-STM32L011F4U6TR (https://eu.mouser.com/ProductDetail/STMicroelectronics/STM32L011F4U6TR) | STMicroelectronics | Mouser | 1.51 | 0.744
ADC | FAN3850AUC16X | 512-FAN3850AUC16X (https://www.mouser.se/ProductDetail/ON-Semiconductor-Fairchild/FAN3850AUC16X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) | ON Semiconductor | Mouser | 1.04 | 0.408
MIC | INMP621ACEZ-R7 | 410-INMP621ACEZ-R7 (https://www.mouser.se/ProductDetail/TDK-InvenSense/INMP621ACEZ-R7) | Invensense | Mouser | 1.46 | 0.679
2xMOS (Class D output stage) | SSM6L61NU | 757-SSM6L61NULF (https://www.mouser.se/ProductDetail/Toshiba/SSM6L61NULF) | Toshiba | Mouser | 0.816 | 0.376
BUCK | TPS62740 | 595-TPS62740DSSR (https://www.mouser.se/ProductDetail/Texas-Instruments/TPS62740DSSR) | Texas Instrumets | Mouser | 1.77 | 1.02
EUROPA | (moon of jupiter)
RADIO(868MHz, Europa) | SPSGRF-868 | 511-SPSGRF-868 (https://www.mouser.se/ProductDetail/STMicroelectronics/SPSGRF-868) | STMicroelectronics | Mouser | 15.75 | 12.24
 |  |  |  | Total: | 29.766 | 21.717
AMERICA, JAPAN
RADIO(915MHz, America) | SPSGRF-915 | 511-SPSGRF-915 (https://www.mouser.se/ProductDetail/STMicroelectronics/SPSGRF-915) | STMicroelectronics | Mouser | 14.11 | 10.75
 |  |  |  | Total: | 28.126 | 20.227

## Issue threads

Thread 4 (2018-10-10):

Check all footprints

Atmelfan, 2018-10-10:
All footprints needs to be verified before being sent to fab.
Leave comment below on checked footprints.

Atmelfan, 2018-11-04:
Checked power supply and SPI on MCU, FPGA and Radio, seems OK.

Closed 2018-11-04.

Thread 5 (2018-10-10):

Add programming connectors for FPGA and MCU

Atmelfan, 2018-10-10:
Both the FPGA and MCU needs a external programming connector. Note that the FPGA programming interface must be shared with the MCU for boot configuration.

Atmelfan, 2018-10-13:
Added SWD connector to MCU and a SPI/Config connector to FPGA according to [Lattice download cable manual](https://www.google.com/url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).

Closed 2018-10-13.

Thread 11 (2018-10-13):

User interface

Atmelfan, 2018-10-13:
We need some kind of user interface.
Since it's not a specified and frankly boring, I'm thinking 2 maybe 3 buttons and a LED?

What does it need to do?
1. Channel up/down
2. Volume up/down
3. Mic on/off
4. Indicate active link

Atmelfan, 2018-10-13:
A lot of indication/notifications can be done with audio-signals (beep-boops) using existing hardware. This requires the FPGA to contain a DDS signal generator exposed to the MCU with variable amplitude/pitch and duration.

Atmelfan, 2018-11-04:
Added a reset bottom and a tiltswitch. The tilt and push switch is connected to 2 spare inputs and the BOOT0 pin. This enables the bootloader by holding the push action while inserting batteries. Once booted BOOT0 can be read as input.

Closed 2018-11-04.

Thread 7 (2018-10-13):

UVLO

Atmelfan, 2018-10-13:
Currently there is no battery under voltage lock-out (UVLO) on the power supply except for a builtin 2.15 V limit in the switch converter.
This is fine for alkaline/nimh batteries but would dangerously discharge a Li-ion cell.

Atmelfan, 2018-10-13:
Li-ion is not a requirement and as such extra UVLO should not be necessary.

Closed 2018-10-13.

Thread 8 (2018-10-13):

FPGA Signals

Atmelfan, 2018-10-13:
What signals are required between MCU and FPGA? Currently only basic configuration signals are connected (can be used as SPI once configuration is done).

What other signal should be shared?
Suggestions:

- [x]  Interrupt request (IRQ)
- [x]  Master/slave control to avoid FPGA/MCU collision in case the FPGA can act as master

More suggestions?

davfr422, 2018-10-13:
There has to some kind of coherence for what's actually going on inside the FPGA during debugging. I guess SPI communication is an alright interface for sharing signals. Let's discuss this more in detail on monday. I feel like I need to better understand the issue in order to give a better answer.

Atmelfan, 2018-10-25:
Added ATT (ATTention) and MINH (Master INHibit) signals between the FPGA and MCU.

Closed 2018-10-25.

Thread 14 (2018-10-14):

FPGA configuration flash

Atmelfan, 2018-10-14:
Our micro does not contain enough flash to contain the configuration image(16 kB vs 102 kB, see below).
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

This can either be solved by:
- A: Adding an external flash/eeprom chip, 0.5 €
- B: Upgrading the MCU for one with 128 kB flash (ex STM32F070RBT6), +0.62 €

Atmelfan, 2018-10-17:
All F0 series STM32s has been added to stdlib. Has not yet changed in schematic. Here is STM32F0 hardware guide: [AN4080](https://www.st.com/content/ccc/resource/technical/document/application_note/c9/19/d7/b8/6b/0e/4c/d3/DM00051986.pdf/files/DM00051986.pdf/jcr:content/translations/en.D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)

Atmelfan, 2018-10-17:
Apparently it did not contain F070 parts... We'll have to add it ourselves.

Atmelfan, 2018-10-25:
Changed to a STM32L082 with 128kB of flash. Should be sufficient for configuration image + application.

Closed 2018-10-25.

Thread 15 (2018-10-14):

ICE40UP5K Dev Kit.

davfr422, 2018-10-14:
I'm thinking about buying one of these for testing the FPGA. I believe this is the best option Lattice offers.
https://www.mouser.se/ProductDetail/Lattice/iCE40UP5K-B-EVN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

Atmelfan, 2018-10-17:
Sounds good for me. Tell Knutsson and then close the issue.

davfr422, 2018-10-17:
Forgot about it today, I'll sent him an email with the product tomorrow. Closing issue when he has ordered it.

Atmelfan, 2018-11-04:
Not related to PCB milestone.

Closed 2018-11-09.

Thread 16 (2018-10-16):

Update rules for altium.

davfr422, 2018-10-16:
Name power nets + add rules for minimun width for net class.
Polygon rules to draw beautiful supply voltage rails.
Clearance.
Any other suggestions? Not really an expert on this topic.

Atmelfan, 2018-10-17:
I suggest these basic rules:
-1: clearance: all, all - 6mil
-2: clearance: inpolygon, all - 10mil
-3: board outline clearance: all - 20mil
-4: trace width: 6mil min, 8mil preferred, 100mil maximum

davfr422, 2018-10-17:
Done and done.

Closed 2018-10-17.

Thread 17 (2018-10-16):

Fix footprints.

davfr422, 2018-10-16:
All footprints are not included by default in git/CDIO. I guess this is because libraries weren't compiled before pushing changes.

Atmelfan, 2018-10-17:
1. Get git for windows
2. Run "git submodule sync; git submodule update"
3. ???
4. Profit

Closed 2018-10-17.

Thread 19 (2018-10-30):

USB bootloader support

Atmelfan, 2018-10-30:
It would be nice to be able to use builtin USB bootloader.
To use it we need to add a USB connector (obviously) and a switch to the BOOT0 pin.

Can be added if time allows.

Atmelfan, 2018-11-04:
USB hardware requires >3V to operate. A separate USB powered 3.3V regulator could supply the VDD_USB through a diode-OR (VDD_USB must always be connected to VDD or higher) to enable USB functionality in the future.

Closed 2018-11-04.

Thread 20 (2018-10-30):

Create Altium BOM

Atmelfan, 2018-10-30:
Create a proper altium BOM using its activeBOM feauture.
Add both Mouser, RS and Elfa links when possible so that Knutsson doesn't have to do it.

Atmelfan, 2018-12-13:
Fixed a long time ago.

Closed 2018-12-13.

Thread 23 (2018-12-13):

Fix joystick pinout

Atmelfan, 2018-12-13:
The joystick footprint has a faulty pinout. The top right pin is set as shield but us actually common.

This results in a short from VSYS_1V8 and GND.

Closed 2020-01-28.

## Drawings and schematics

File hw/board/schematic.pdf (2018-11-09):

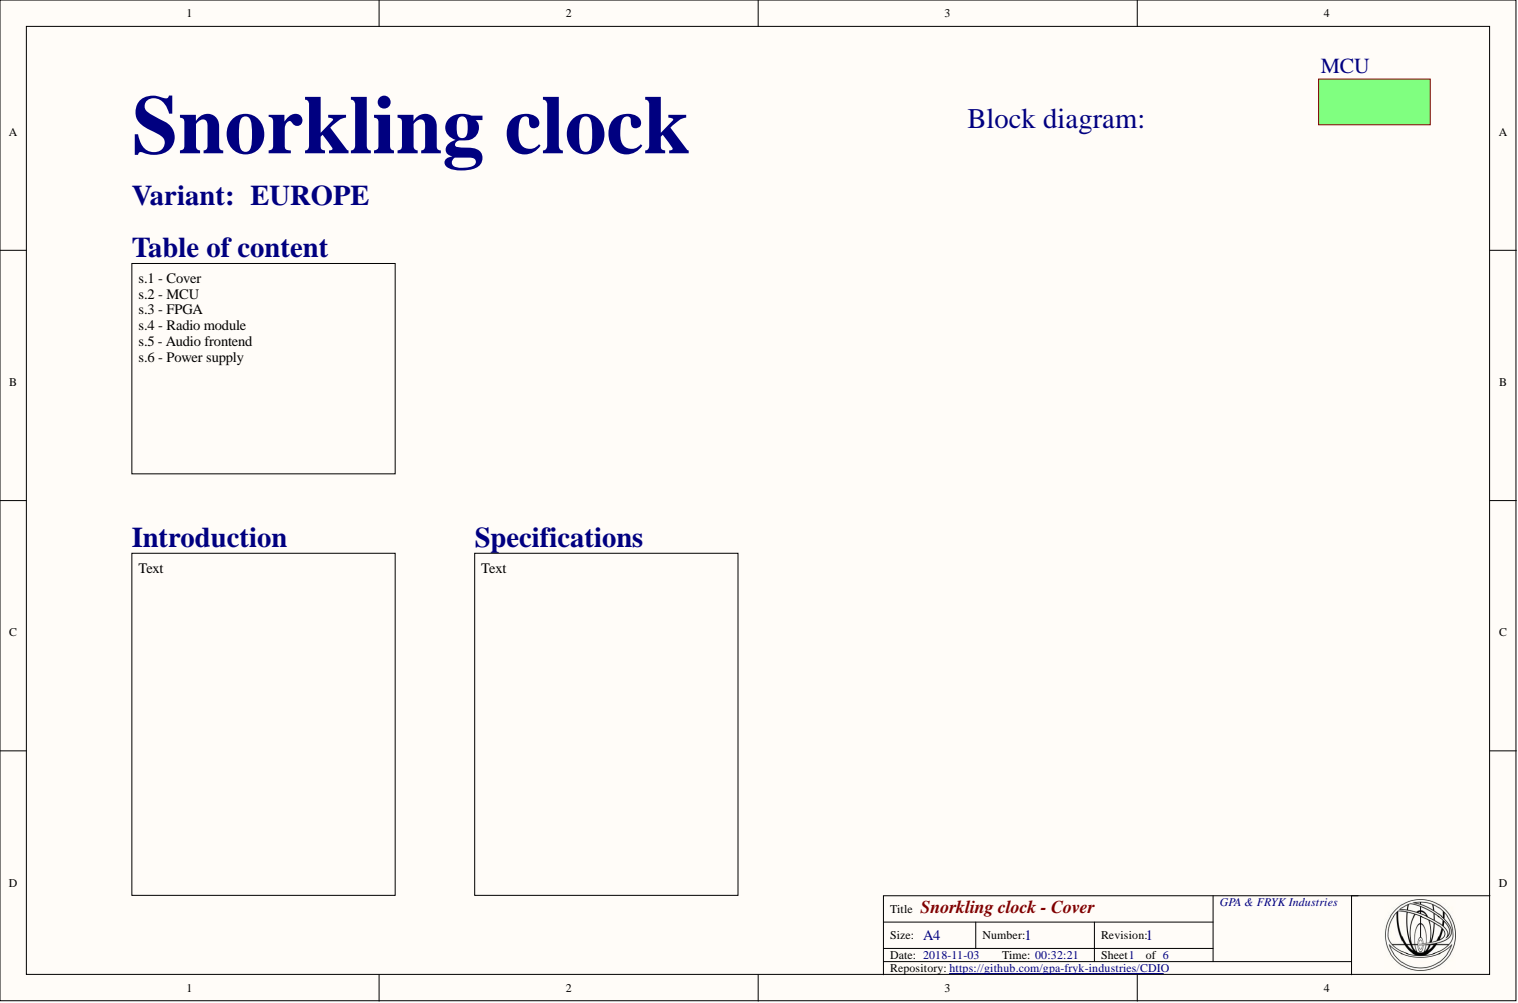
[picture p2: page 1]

Title Snorkling clock - Cover | GPA & FRYK Industries

Size: A4 | Number: | Revision:
Date: 2018-11-03 Time: 00:32:21 | | Sheet of

Repository: https://github.com/gpa-fryk-industries/CDIO

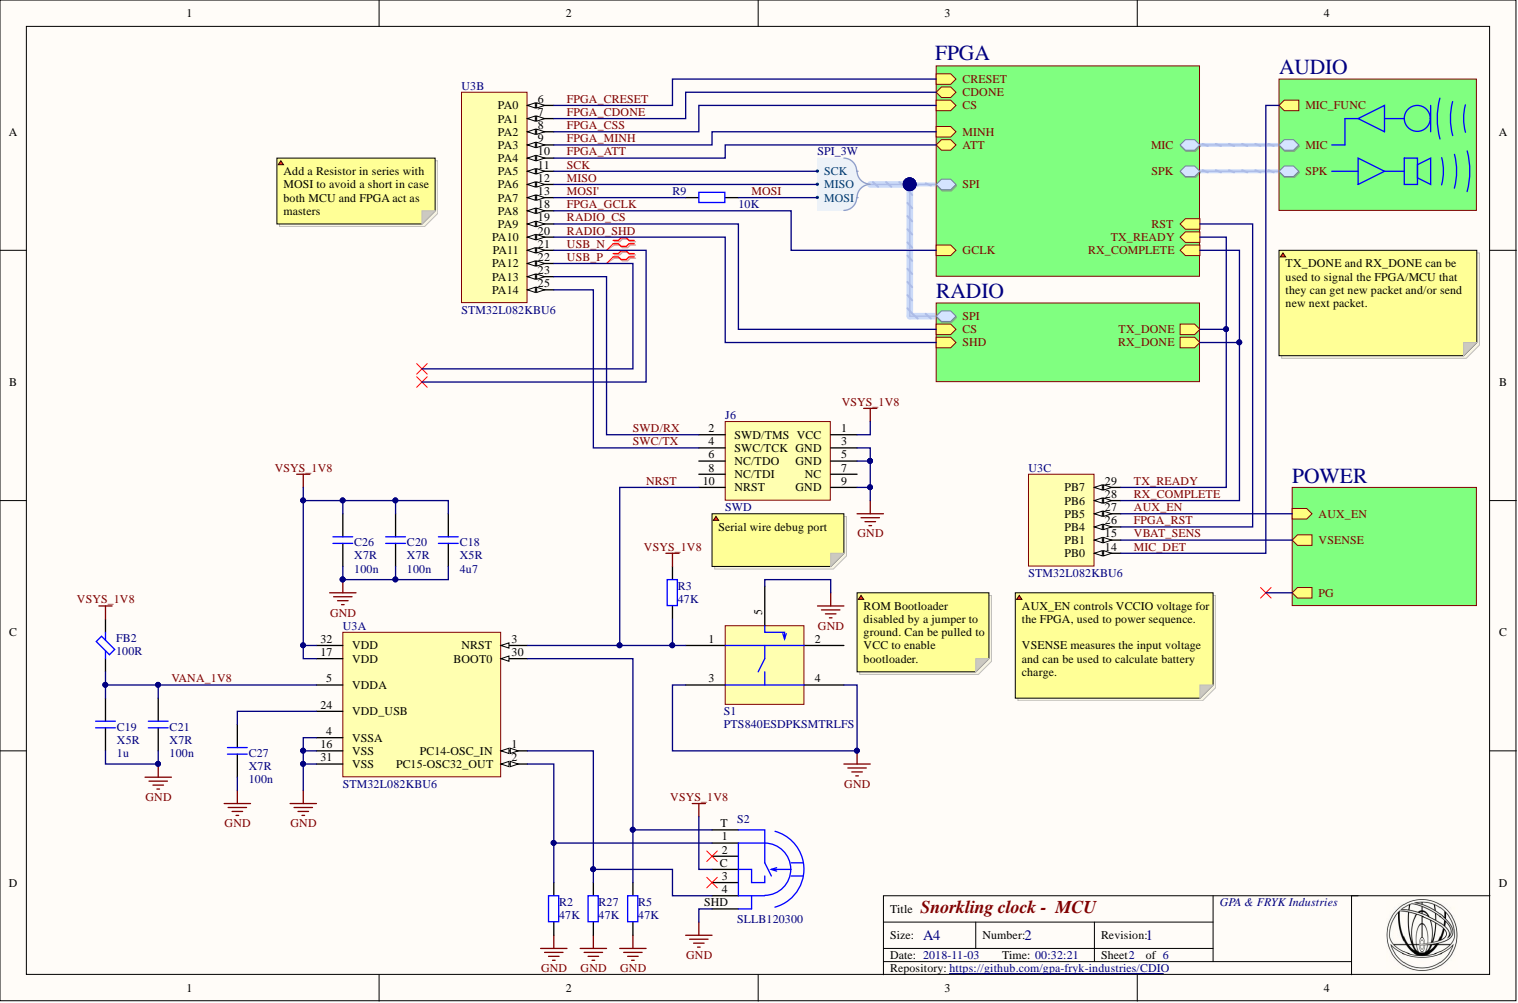
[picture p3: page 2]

CRESET CDONE

Add a Resistor in series with
MOSI to avoid a short in case
both MCU and FPGA act as
masters

PA12 | 22 | USB_P
PA13 | 23

TX_DONE and RX_DONE can be
used to signal the FPGA/MCU that
they can get new packet and/or send
new next packet.

RADIO

SWD
Serial wire debug port

ROM Bootloader
disabled by a jumper to
ground. Can be pulled to
VCC to enable
bootloader.

AUX_EN controls VCCIO voltage for
the FPGA, used to power sequence.

VDD 32 | PC14-OSC_IN

VSENSE measures the input voltage
and can be used to calculate battery
charge.

VDDA 5 | 1

VDD_USB 24

VSS 16

https://github.com/gpa-fryk-industries/CDIO

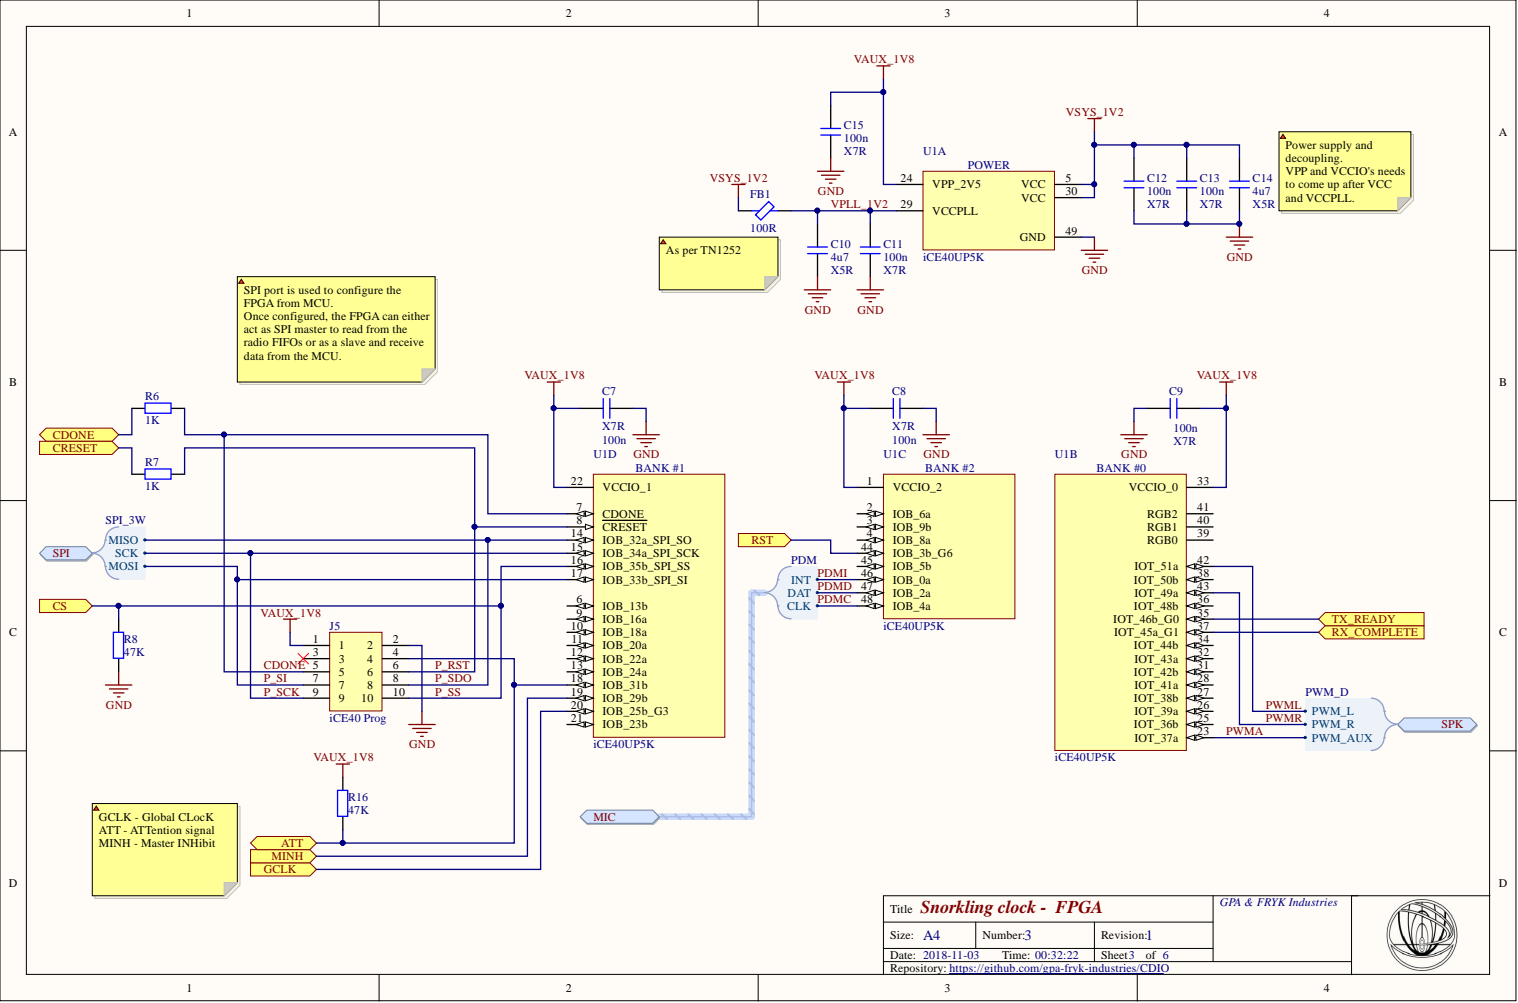
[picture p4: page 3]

SPI port is used to configure the
FPGA from MCU.
Once configured, the FPGA can either
act as SPI master to read from the
radio FIFOs or as a slave and receive
data from the MCU.

P_SCK | 9 9 10 | 10 | P_SS | IOB_29b 19

IOB_25b_G3 20

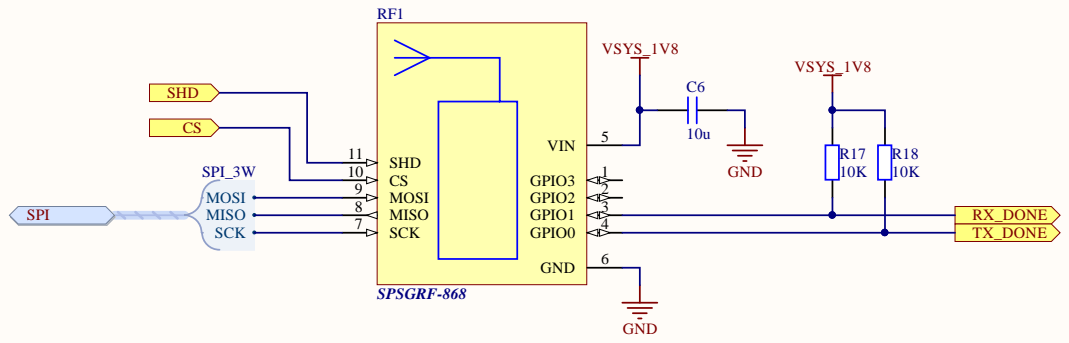
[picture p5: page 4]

Snorkling clock - Radio module
Title

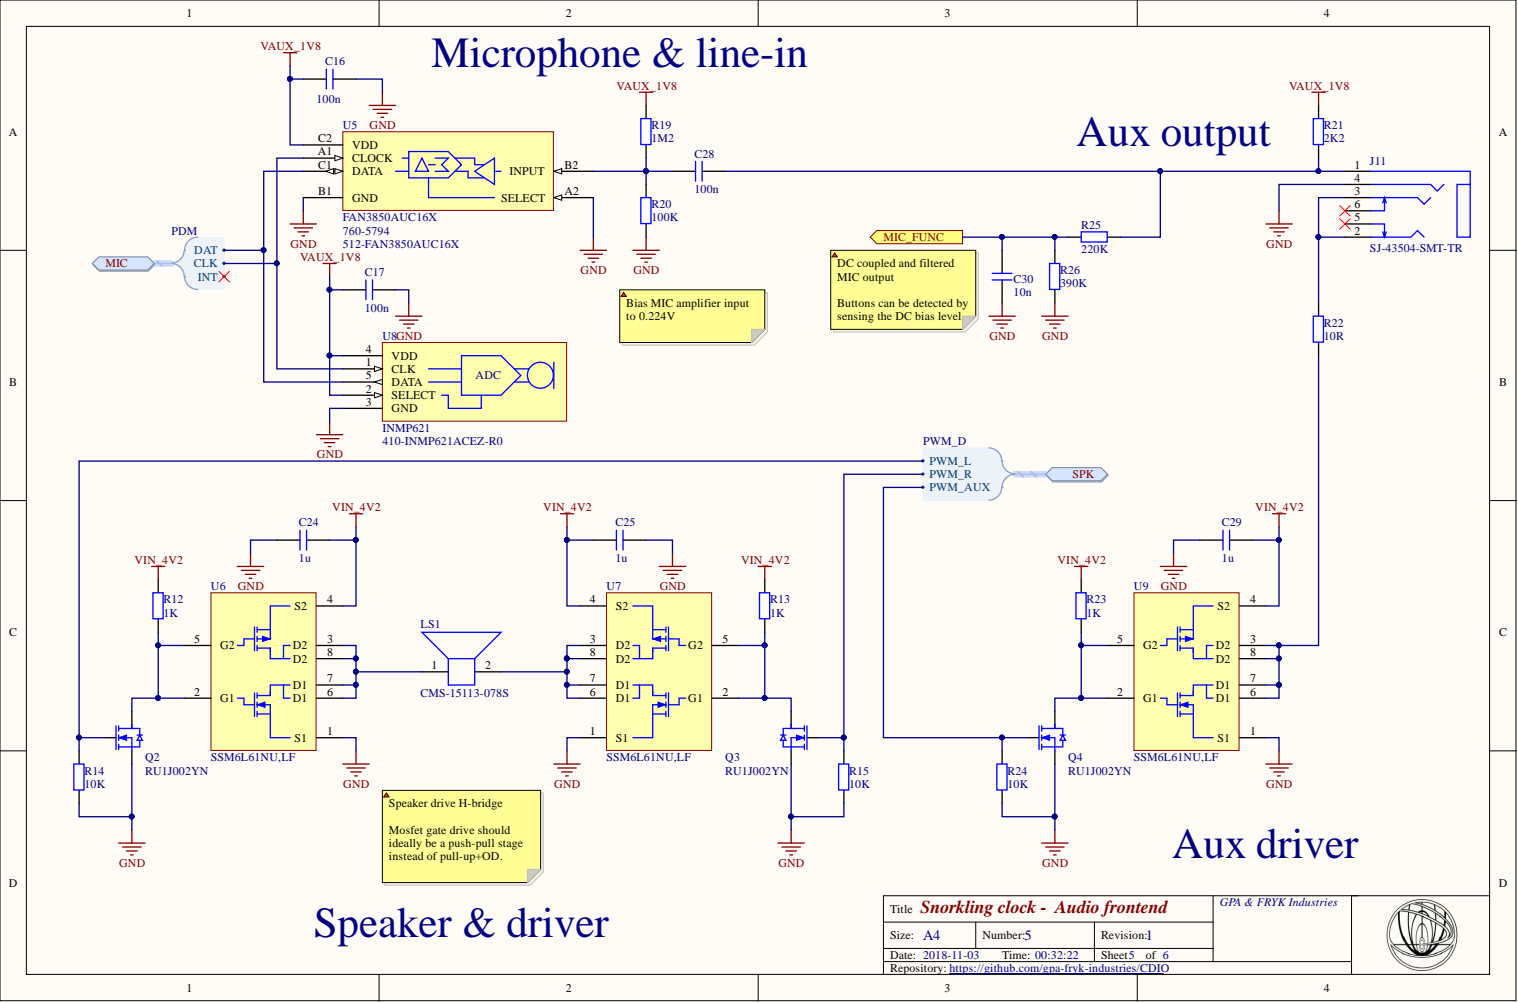
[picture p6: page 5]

DATA C1

DC coupled and filtered
MIC output

Bias MIC amplifier input

Buttons can be detected by
sensing the DC bias level.

CLK 1

SELECT 2
GND 3

Mosfet gate drive should
ideally be a push-pull stage
instead of pull-up+OD.
Speaker & driver

Snorkling clock - Audio frontend
Title

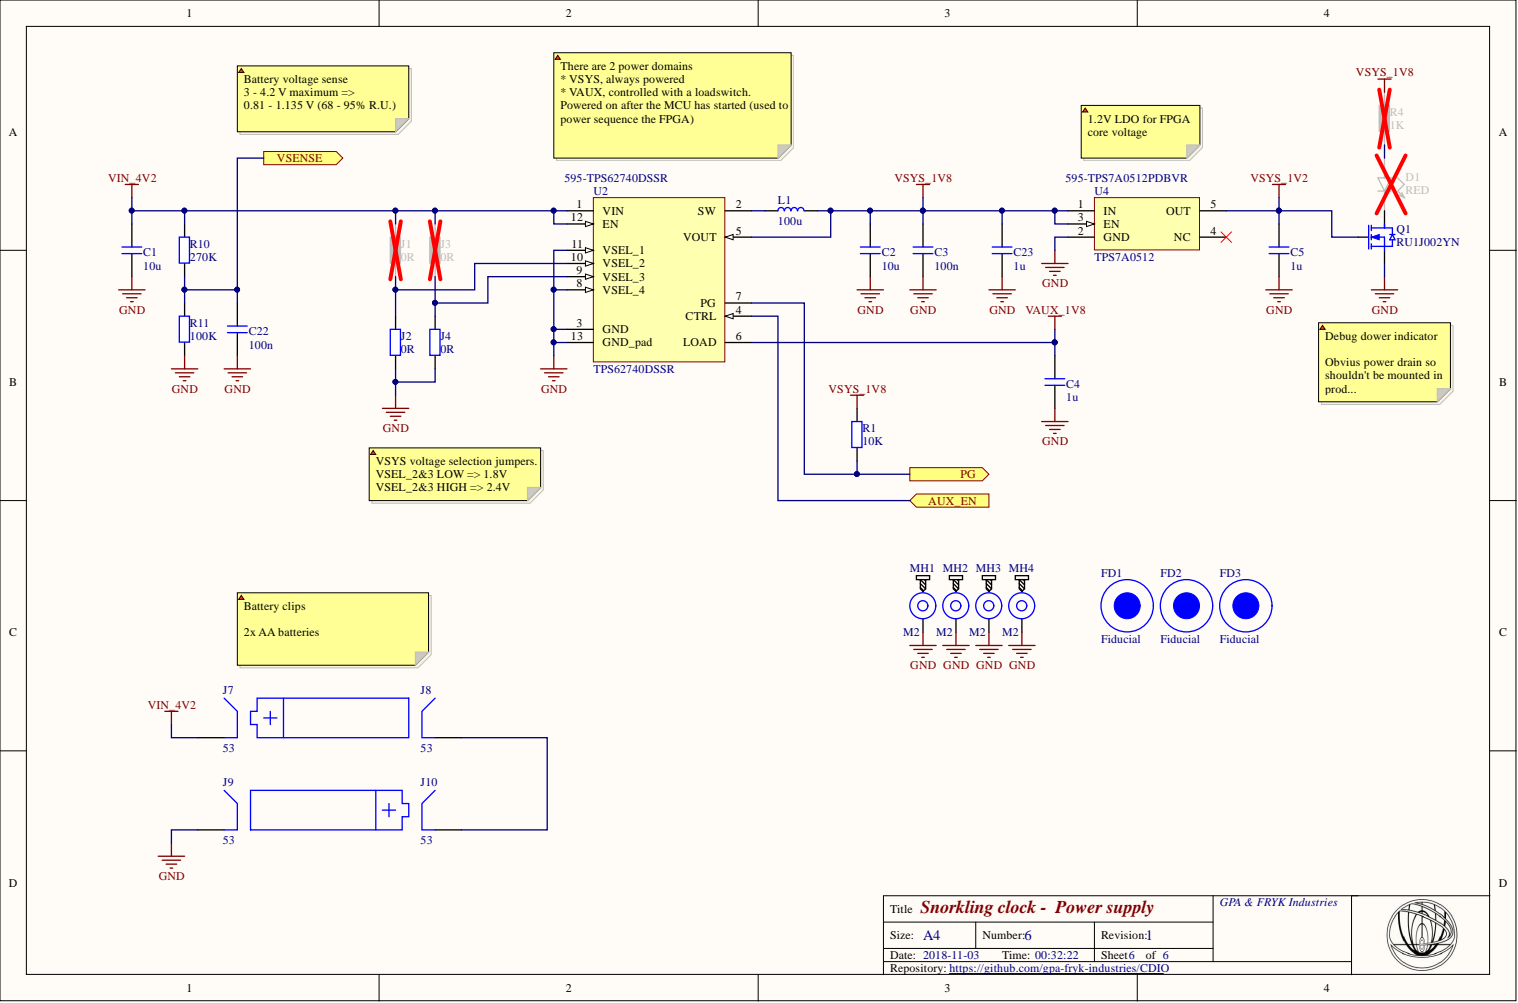
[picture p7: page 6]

There are 2 power domains
* VSYS, always powered
* VAUX, controlled with a loadswitch.
Powered on after the MCU has started (used to
power sequence the FPGA)

Obvius power drain so
shouldn't be mounted in
prod...

VSYS voltage selection jumpers.
VSEL_2&3 LOW => 1.8V
VSEL_2&3 HIGH => 2.4V

GND GND

Snorkling clock - Power supply
Title

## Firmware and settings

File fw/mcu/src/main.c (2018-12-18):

#include <stdio.h>
#include <libopencm3/cm3/nvic.h>
#include <libopencm3/stm32/rcc.h>
#include <libopencm3/stm32/gpio.h>
#include <libopencm3/stm32/usart.h>
#include <libopencm3/stm32/i2c.h>
#include <libopencm3/stm32/spi.h>
#include <libopencm3/stm32/exti.h>
#include <libopencm3/stm32/l0/timer.h>




#include "fdt/fdt_utils.h"
#include "fdt/dtb_parser.h"
#include "fpga/fpga_config.h"
#include "pins.h"
#include "dumb_delay.h"
#include "radio/SPIRIT1_Library/Inc/SPIRIT_Config.h"
#include "radio/spirit1.h"
#include "fpga/fpga.h"

FDT_FILE(config);

bool serial_enabled = false;

extern uint8_t fpga_conf[];
extern uint8_t fpga_conf_end;

/**
 * Initialize clocks
 */
static void init_clocks(void)
{
    /* Set sysclock to internal 16MHz oscillator*/
    rcc_set_sysclk_source(RCC_HSI16);
    RCC_CR &= ~RCC_CR_HSI16DIVEN;

    rcc_periph_clock_enable(RCC_GPIOA);
    //rcc_periph_clock_enable(RCC_AF);


    /* PA_FPGA_GCLK, MCO output */
    gpio_mode_setup(GPIOA, GPIO_MODE_AF, GPIO_PUPD_NONE, PA_FPGA_GCLK);
    gpio_set_output_options(GPIOA, GPIO_OTYPE_PP, GPIO_OSPEED_100MHZ, PA_FPGA_GCLK);
    gpio_set_af(GPIOA, GPIO_AF0, PA_FPGA_GCLK);

    /* Configure MCO = sysclk / 4 = 4 MHz */
    //rcc_set_mco(RCC_CFGR_MCO_SYSCLK); //Doesn't work for shit,
    RCC_CFGR |= (RCC_CFGR_MCO_SYSCLK << RCC_CFGR_MCO_SHIFT) | (RCC_CFGR_MCOPRE_DIV1 << 28);

}

/**
 * Initialize gpios (not pins!)
 */
void init_gpio(){
    /* Enable GPIO clocks */

    rcc_periph_clock_enable(RCC_GPIOB);
}

/**
 * Initialize SPI pins and relevant chip select pins
 */
void init_spi_pins(){

    /* PA_SPI_SCK pin */
    gpio_mode_setup(GPIOA, GPIO_MODE_OUTPUT, GPIO_PUPD_PULLDOWN, PA_SPI_SCK);
    gpio_set_output_options(GPIOA, GPIO_OTYPE_PP, GPIO_OSPEED_HIGH, PA_SPI_SCK);
    gpio_clear(GPIOA, PA_SPI_SCK);
    //gpio_set_af(GPIOA, 0, PA_SPI_SCK);

    /* PA_SPI_MOSI pin */
    gpio_mode_setup(GPIOA, GPIO_MODE_OUTPUT, GPIO_PUPD_PULLDOWN, PA_SPI_MOSI);
    gpio_set_output_options(GPIOA, GPIO_OTYPE_PP, GPIO_OSPEED_HIGH, PA_SPI_MISO);
    gpio_clear(GPIOA, PA_SPI_MOSI);
    //gpio_set_af(GPIOA, 0, PA_SPI_MOSI);

    /* PA_SPI_MISO pin */
    gpio_mode_setup(GPIOA, GPIO_MODE_INPUT, GPIO_PUPD_PULLDOWN, PA_SPI_MISO);
    //gpio_set_af(GPIOA, 0, PA_SPI_MISO);


    /** FPGA **/
    /* PA_FPGA_CSS pin */
    gpio_mode_setup(GPIOA, GPIO_MODE_OUTPUT, GPIO_PUPD_PULLDOWN, PA_FPGA_CSS);
    gpio_set_output_options(GPIOA, GPIO_OTYPE_PP, GPIO_OSPEED_HIGH, PA_FPGA_CSS);
    gpio_clear(GPIOA, PA_FPGA_CSS); /* Select fpga */

    /** RADIO **/
    /* PA_RADIO_CS pin */
    gpio_mode_setup(GPIOA, GPIO_MODE_OUTPUT, GPIO_PUPD_PULLDOWN, PA_RADIO_CS);
    gpio_set_output_options(GPIOA, GPIO_OTYPE_PP, GPIO_OSPEED_HIGH, PA_RADIO_CS);
    gpio_set(GPIOA, PA_RADIO_CS); /* Deselect radio */

    /* PA_RADIO_SHD pin */
    gpio_mode_setup(GPIOA, GPIO_MODE_OUTPUT, GPIO_PUPD_NONE, PA_RADIO_SHD);
    gpio_set_output_options(GPIOA, GPIO_OTYPE_PP, GPIO_OSPEED_HIGH, PA_RADIO_SHD);
    gpio_set(GPIOA, PA_RADIO_SHD); /* Disable radio */
    _dumb_delay_us(100);
    gpio_clear(GPIOA, PA_RADIO_SHD); /* Enable radio */


}

/**
 * Shift 8bit to FPGA
 * @param b
 */
void fpga_shift8(uint8_t b){

    /* TODO: refactor this shit */
    for (int i = 0; i < 8; ++i) {

        /* Set SCK LOW */
        gpio_clear(GPIOA, PA_SPI_SCK);

        /* Output high bit to MOSI */
        if(b & 0x80)
            gpio_set(GPIOA, PA_SPI_MOSI);
        else
            gpio_clear(GPIOA, PA_SPI_MOSI);

        /* Wait half t_sck */
        _dumb_delay_cycles(8);

        /* Set SCK HIGH */
        gpio_set(GPIOA, PA_SPI_SCK);

        /* Wait half t_sck */

        _dumb_delay_cycles(8);


        /* Shift up by one */
        b <<= 1;
    }
}

bool config_fpga(){
    /* Pull select low */
    gpio_clear(GPIOA, PA_FPGA_CSS);

    /* Generate a creset pulse */
    _dumb_delay_us(20);
    gpio_clear(GPIOA, PA_FPGA_CRESET);
    _dumb_delay_us(20);
    gpio_set(GPIOA, PA_FPGA_CRESET);

    /* Wait atleast 1200us for the FPGA to clear its memory */
    _dumb_delay_us(1200);

    /* Pull CSS high, send 8 dummy bits, pull SCK low*/
    gpio_set(GPIOA, PA_FPGA_CSS);
    fpga_shift8(0x00);
    gpio_clear(GPIOA, PA_FPGA_CSS);

    /* Send configuration image */
    for (unsigned long j = 0; j < (&fpga_conf_end - fpga_conf); ++j) {
        fpga_shift8(((uint8_t*)fpga_conf)[j]);
    }

    /*Send 104 (> 100) dummy clocks */
    gpio_set(GPIOA, PA_FPGA_CSS);
    for (int i = 0; i < 13; ++i) {
        fpga_shift8(0x00);
    }

    bool cdone = (gpio_port_read(GPIOA) & PA_FPGA_CDONE) != 0;

    /* Send 56 clocks */
    for (int i = 0; i < 7; ++i) {
        fpga_shift8(0x00);
    }

    /* CDONE should be high or we've fucked up */
    return cdone;
}

bool init_fpga(bool enable){

    /* PB_PMIC_AUX_EN pin */
    gpio_mode_setup(GPIOB, GPIO_MODE_OUTPUT, GPIO_PUPD_NONE, PB_PMIC_AUX_EN);
    gpio_set_output_options(GPIOB, GPIO_OTYPE_PP, GPIO_OSPEED_LOW, PB_PMIC_AUX_EN);
    gpio_clear(GPIOB, PB_PMIC_AUX_EN);

    /* PA_FPGA_CRESET pin */
    gpio_mode_setup(GPIOA, GPIO_MODE_OUTPUT, GPIO_PUPD_NONE, PA_FPGA_CRESET);
    gpio_set_output_options(GPIOA, GPIO_OTYPE_PP, GPIO_OSPEED_LOW, PA_FPGA_CRESET);
    gpio_clear(GPIOA, PA_FPGA_CRESET);

    /* PB_FPGA_RST pin */
    gpio_mode_setup(GPIOB, GPIO_MODE_OUTPUT, GPIO_PUPD_NONE, PB_FPGA_RST);
    gpio_set_output_options(GPIOB, GPIO_OTYPE_PP, GPIO_OSPEED_LOW, PB_FPGA_RST);
    gpio_clear(GPIOB, PB_FPGA_RST);

    /* PA_FPGA_CDONE pin */
    gpio_mode_setup(GPIOA, GPIO_MODE_INPUT, GPIO_PUPD_PULLUP, PA_FPGA_CDONE);

    /* Enable power to FPGA but keep in reset */
    if(enable){
        gpio_set(GPIOB, PB_PMIC_AUX_EN);
    }else{
        gpio_clear(GPIOB, PB_PMIC_AUX_EN);
    }
    gpio_clear(GPIOA, PA_FPGA_CRESET);

    return true;
}

/**
 * Initialize hardware SPI for use with FPGA and the Radio.
 * NOTE! Must be done AFTER FPGA initialization due to some weird spi things
 * required by said initialization which is bitbanged.
 */
static void init_spi(){

    /* Reinitialize SPI pins to AF mode */
    /* PA_SPI_SCK pin */
    gpio_mode_setup(GPIOA, GPIO_MODE_AF, GPIO_PUPD_PULLDOWN, PA_SPI_SCK);
    gpio_set_output_options(GPIOA, GPIO_OTYPE_PP, GPIO_OSPEED_HIGH, PA_SPI_SCK);
    gpio_set_af(GPIOA, GPIO_AF0, PA_SPI_SCK);

    /* PA_SPI_MOSI pin */
    gpio_mode_setup(GPIOA, GPIO_MODE_AF, GPIO_PUPD_PULLDOWN, PA_SPI_MOSI);
    gpio_set_output_options(GPIOA, GPIO_OTYPE_PP, GPIO_OSPEED_HIGH, PA_SPI_MISO);
    gpio_set_af(GPIOA, GPIO_AF0, PA_SPI_MOSI);

    /* PA_SPI_MISO pin */
    gpio_mode_setup(GPIOA, GPIO_MODE_AF, GPIO_PUPD_PULLDOWN, PA_SPI_MISO);
    gpio_set_af(GPIOA, GPIO_AF0, PA_SPI_MISO);

    /* Enable clock */
    rcc_periph_clock_enable(RCC_SPI1);

    /* Reset SPI, defaults to disabled */
    spi_reset(SPI1);

    /* Init SPI to  */
    spi_init_master(SPI1, SPI_CR1_BAUDRATE_FPCLK_DIV_64, SPI_CR1_CPOL_CLK_TO_0_WHEN_IDLE,
                    SPI_CR1_CPHA_CLK_TRANSITION_1, SPI_CR1_DFF_8BIT, SPI_CR1_MSBFIRST);

    /* We'll control chip select. NSS(internal) needs to be set high because it's to retarded to do it itself */
    spi_enable_software_slave_management(SPI1);
    spi_set_nss_high(SPI1);

    /* Enable SPI */
    spi_enable(SPI1);
}

static void init_serial(void)
{
    /* Configure serial data pins*/
    gpio_mode_setup(GPIOA, GPIO_MODE_AF, GPIO_PUPD_NONE, PA_SERIAL_RXD);
    gpio_mode_setup(GPIOA, GPIO_MODE_AF, GPIO_PUPD_NONE, PA_SERIAL_TXD);
    gpio_set_output_options(GPIOA, GPIO_OTYPE_PP, GPIO_OSPEED_HIGH, PA_SERIAL_RXD | PA_SERIAL_TXD);
    gpio_set_af(GPIOA, GPIO_AF1, PA_SERIAL_RXD | PA_SERIAL_TXD);

    /* Serial */
    rcc_periph_clock_enable(RCC_USART1);

    /* Configure USART peripheral, 9800 8N1 */
    usart_set_mode(USART1, USART_MODE_TX_RX);
    usart_set_baudrate(USART1, 9800);
    usart_set_databits(USART1, 8);
    usart_set_parity(USART1, USART_PARITY_NONE);
    usart_set_stopbits(USART1, USART_STOPBITS_1);

    /* Enable */
    usart_enable(USART1);
    serial_enabled = true;
}

void init_radio(){
    /* PB_RADIO_TXR pin */
    gpio_mode_setup(GPIOB, GPIO_MODE_INPUT, GPIO_PUPD_PULLUP, PB_RADIO_TXR);

    /* Configure EXTI7 source. */
    nvic_enable_irq(NVIC_EXTI4_15_IRQ);
    exti_select_source(EXTI7, GPIOB);

    /* Interrupt on falling edge */
    exti_set_trigger(EXTI7, EXTI_TRIGGER_FALLING);

    /* Enable interrupt */
    exti_enable_request(EXTI7);
}

void exti4_15_isr(void)
{
    if(exti_get_flag_status(EXTI7)){
        exti_reset_request(EXTI7);

        radio_interrupt();
    }
}


void init_lptim(){

    /* Enable LPTIM1 clock */
    rcc_periph_clock_enable(RCC_LPTIM1);

    /* Reset LPTIM1 to defaults. */
    rcc_periph_reset_pulse(RST_LPTIM1);


    /* Reset count */
    timer_set_counter(LPTIM1_BASE, 0);




    /* Clear current count */
    LPTIM1_CNT = 0;

    /* Prescale with 128 */
    LPTIM1_CFGR |= LPTIM_CFGR_PRESC_128;

    /* Start timer */
    LPTIM1_CR |= LPTIM_CR_ENABLE;

    /* Enable LPTIM1 interrupts. */
    nvic_enable_irq(NVIC_LPTIM1_IRQ);
    nvic_set_priority(NVIC_LPTIM1_IRQ, 1);
}

void lptim1_isr(void){

}

#ifdef ENABLE_SEMIHOSTING
    extern void initialise_monitor_handles(void); /* prototype */
#   warning "Semihosting is ENABLED! Will not run without debugger!"
#endif

int main(){


#ifdef ENABLE_SEMIHOSTING
    initialise_monitor_handles();
#endif


    init_clocks();

    /* Init GPIOs with clocks */
    init_gpio();

    /* Parse device tree */
    fdt_header_t* fdt = &config;
    fdt_token* root = fdt_get_tokens(fdt);

    /* Check the 'enable-serial' tag and init usart if found */
    if(fdt_node_get_prop(fdt, root, "enable-serial", false)){
        init_serial();
    }

    /* Init SPI pins for FPGA configuration */
    init_spi_pins();

    /* Check the 'enable-fpga' tag and power-up/configure if found */
    if(fdt_node_get_prop(fdt, root, "enable-fpga", false)){
        init_fpga(true);
        if(fdt_node_get_prop(fdt, root, "config-fpga", false)){
            config_fpga();
        }
    }else{
        init_fpga(false);
    }

    /* Deselect FPGA and Radio */
    gpio_set(GPIOA, PA_FPGA_CSS);
    gpio_set(GPIOA, PA_RADIO_CS);

    /* Init hw SPI (note: reinitializes some SPI pins, cannot be called before config_fpga()) */
    init_spi();
    spi_set_nss_high(SPI1);

    _dumb_delay_us(100);

    //SpiritSpiCommandStrobes(COMMAND_SRES);

    //SpiritManagementWaExtraCurrent();

    //SpiritRadioSetXtalFrequency(50000000);

    /* Init Radio */
    //radio_init();

    char wtest[] = {1, 2, 3, 4, 5, 6, 7, 8, 9, 10, 11, 12};
    char rtest[12];

    //radio_send((uint8_t *) test, 12);
    /* Radio stays in LOCKWON state, try to force it to TX state *
     * Doesn't work for shit...
     */
//    StatusBytes s;
//    do{
//        s = RadioSpiCommandStrobes(COMMAND_TX);
//    }while(s.MC_STATE != MC_STATE_TX);

    fpga_reset();

    /* Loop */
    while(true){

        for (int i = 0; i < 12; ++i) {

            /*  */
            fpga_write((uint8_t *) &wtest[i], 2);
            _dumb_delay_us(10000);

        }



        /*  */
        fpga_read((uint8_t *) &rtest, 12);


    }

    return 0;
}

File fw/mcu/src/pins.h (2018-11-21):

//
// Created by atmelfan on 11/20/18.
//

#ifndef PROJECT_PINS_H
#define PROJECT_PINS_H

/**
 * FPGA Pins
 */
#define PA_FPGA_CRESET  GPIO0 /*Config reset*/
#define PA_FPGA_CDONE   GPIO1 /*Config done*/
#define PA_FPGA_CSS     GPIO2 /*Config chip select*/
#define PA_FPGA_MINH    GPIO3 /*Master INHibit*/
#define PA_FPGA_ATT     GPIO4 /*ATTention*/
#define PA_FPGA_GCLK    GPIO8 /*Clock*/

#define PB_FPGA_RST     GPIO4 /*Reset*/

/**
 * PMIC pins
 */
#define PB_PMIC_AUX_EN  GPIO5
#define PB_PMIC_VSENS   GPIO1

/**
 * Radio pins
 */
#define PA_RADIO_CS     GPIO9
#define PA_RADIO_SHD    GPIO10

#define PB_RADIO_TXR    GPIO7
#define PB_RADIO_RXC    GPIO6

/**
 * MIC pins
 */
#define PB_MIC_DET      GPIO0

/**
 * SPI pins
 */
#define PA_SPI_SCK      GPIO5
#define PA_SPI_MISO     GPIO6
#define PA_SPI_MOSI     GPIO7


/**
 * Serial pins (CONFLICTS WITH SWD!)
 */
#define PA_SERIAL_RXD GPIO13
#define PA_SERIAL_TXD GPIO14

#endif //PROJECT_PINS_H

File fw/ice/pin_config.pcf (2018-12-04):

###IOSet List 9

# Control
set_io CLK_MCO 20
set_io ATT 18
set_io RST 44
set_io MINH 20

# Microphone
set_io MIC_DAT 47
set_io MIC_CLK 48

# Speakers
set_io SPK_R 43
set_io SPK_L 42
set_io SPK_A 23

# Radio
set_io RAD_TXR 35
set_io RAD_RXC 37

# SPI 
set_io SPI_SO 14
set_io SPI_SCK 15
set_io SPI_SS 16
set_io SPI_SI 17

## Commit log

2018-09-19 Adding documents
    Documentation for the projekt. Subject to change.
    [projektgrupp6_tidsplan.xlsx]
2018-09-20 Initial HW design
    [audio.SchDoc, board.PrjPCB, cover.SchDoc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]
2018-09-20 Added outjobs for documentation and BOM. Also fixed some shit in gitignore.
    [board.PrjPCB]
2018-09-23 Projektplan v1.0, Kravspec v2.0
    Se rubrik
    [projektgrupp6_tidsplan.xlsx]
2018-09-23 Revert "Merge branch 'master' of https://github.com/gpa-fryk-industries/CDIO"
    This reverts commit c173a9ac261cfe2d504fa38be32b72ec8e2ed8d6, reversing
    changes made to 495d65925257bfcdccf4a69d03a2d28c8b9da1c7.
    [audio.SchDoc, board.PrjPCB, cover.SchDoc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]
2018-09-23 Revert "Revert "Merge branch 'master' of https://github.com/gpa-fryk-industries/CDIO""
    This reverts commit c7c30cd62f2f7545880bf931c0d0ef860afabbe8.
    [audio.SchDoc, board.PrjPCB, cover.SchDoc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]
2018-09-23 Uppdaterat tidsplan
    La till timmar för v.38
    [projektgrupp6_tidsplan.xlsx]
2018-09-24 Updated component excel sheet and removed office garbage from .gitignore
    [iq.xlsx]
2018-09-24 Removed charger from block diagram
    [cover.SchDoc]
2018-10-01 Updated stdlib and started FPGA and PSU section
    [board.PrjPCB, fpga.SchDoc, power.SchDoc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]
2018-10-01 Updated FPGA and stuff
    [fpga.SchDoc, mcu.SchDoc, power.SchDoc]
2018-10-04 Documentation
    Updated documents
    [projektgrupp6_tidsplan.xlsx]
2018-10-09 Added altium workspace
    [board.PrjPCB, cover.SchDoc]
2018-10-09 Did a lot of schematic work
    [audio.SchDoc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]
2018-10-09 Don't know
    [fpga.SchDoc]
2018-10-09 No idea
    [board.PrjPCB, mcu.SchDoc]
2018-10-13 Added battery clips and additional decoupling for LDO
    [power.SchDoc]
2018-10-13 Added programming connectors to FPGA and MCU
    [fpga.SchDoc, mcu.SchDoc]
2018-10-13 Added speaker and speaker drive circuit
    [audio.SchDoc]
2018-10-13 Updated stdlib
    [power.SchDoc]
2018-10-13 Did a bunch of stuff. Also updated schematics prints.
    [board.PrjPCB, fpga.SchDoc, mcu.SchDoc]
2018-10-17 Made a layout design for the power circuitry
    [board.PcbDoc, board.PcbLib, board.PrjPCB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]
2018-10-17 Fixed documents
    Updated time report for me and made some edits to the project plan.
    [projektgrupp6_tidsplan.xlsx]
2018-10-25 Updated stdlib with STM32L082
2018-10-28 Added net names to previously unnamed nets
    [audio.SchDoc, fpga.SchDoc, mcu.SchDoc]
2018-10-28 Replaced NT4003 Nch MOSFET with RU1J002YN
    [audio.SchDoc, power.SchDoc]
2018-10-28 Added FPGA_RST signal and MCU reset button
    [fpga.SchDoc, mcu.SchDoc]
2018-10-28 Fixed missing signals and buttons
    [audio.SchDoc, board.PcbDoc, board.PrjPCB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]
2018-10-29 Added M2 mounting holes in schematic and did layout work
    [board.PcbDoc, power.SchDoc]
2018-10-29 Layout work and updated schematics
    [board.PcbDoc]
2018-10-29 Layout work and switched around PWMA and PWMR
    [board.PcbDoc, fpga.SchDoc]
2018-10-30 Moved around PWML and PWMR to make layout easier
    [fpga.SchDoc]
2018-10-30 Layout mostly completed
    [board.PcbDoc]
2018-10-30 Updated schematics
2018-11-02 Added lever & push switch
    [mcu.SchDoc]
2018-11-02 Added fiducials
    [power.SchDoc]
2018-11-02 Finished up layout, tidied a bit
    [board.PcbDoc, board.PrjPCB]
2018-11-04 Finished layout and generated gerbers
    [board.GBL, board.GBO, board.GBP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]
2018-11-04 Small fixes, version 1.0
    [board.PcbDoc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]
2018-11-04 Fixed VDD_USB not being connected to VDD, version 1.1
    [board.PcbDoc, board.PrjPCB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]
2018-11-05 Added component supply links
    [audio.SchDoc, board.PrjPCB, fpga.SchDoc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]
2018-11-07 Added FFT blocks and VAD basic modules for FPGA
    [audio.SchDoc, board.PrjPCB, bom.xls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]
2018-11-09 Changed MCU to STM32L082KBU, initial fpga config support
2018-12-12 Added HW SPI initialization
2018-12-12 Added Spirit1 SPI communication stubs
2018-12-12 Fixed Radio SPI not using correct mode (Doh!) and started initialization.
    [main.c]
2018-12-12 Added test case for ADPCM
2018-12-15 Tried to fix radio not accepting commands. Still not working.
    [main.c]
